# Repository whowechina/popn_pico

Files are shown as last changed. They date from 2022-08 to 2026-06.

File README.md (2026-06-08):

# Popn Pico - Pop'n Music Style Mini Controller
[点这里可以切换到中文版](README_CN.md)

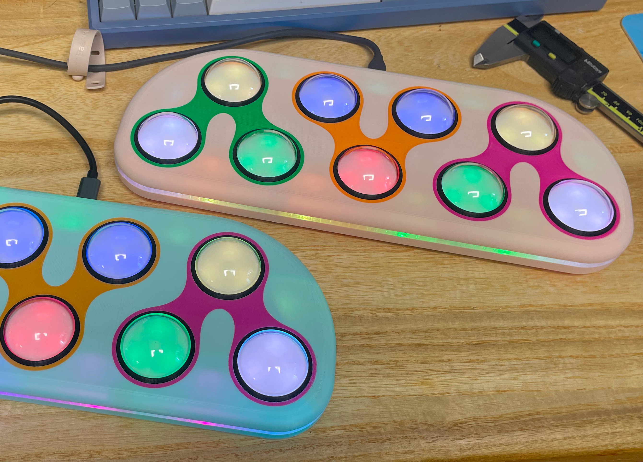
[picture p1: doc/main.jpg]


I've made two generations of Popn Pico. The latest is Popn Pico 2. It's larger than the first generation.

The document here is for the latest generation. The files for the first generation are archived in `Gen1Archive` folder. This is what the first generation looks like.  
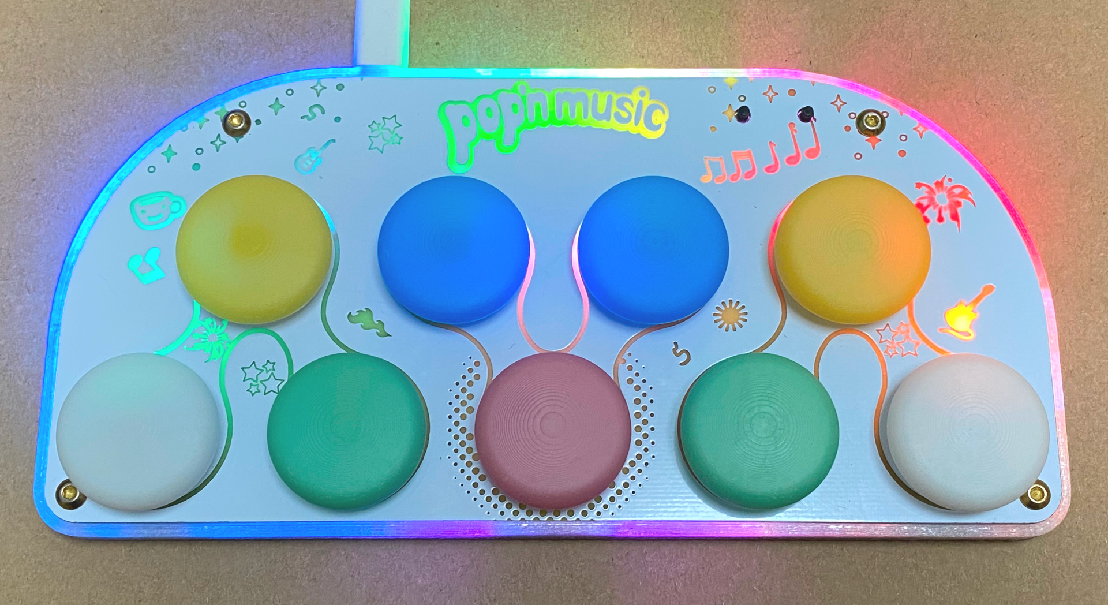
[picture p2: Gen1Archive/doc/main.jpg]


Features:
* It uses self-made 40mm dome buttons.
* Full HID light support.
* Command line for configurations.
* All source files open.

Thanks to many respectful guys/companies who made their tools or materials free or open source (KiCad, OnShape, InkScape, Raspberry things).

Special thanks to community projects and developers.
And also these projects:
* RP_Silicon_KiCad: https://github.com/HeadBoffin/RP_Silicon_KiCad
* Type-C: https://github.com/ai03-2725/Type-C.pretty

## About the License
It's CC-NC. So DIY for yourself and for your friend for free, don't make money from it. And plagiarism that doesn’t even dare to mention the original author is not acceptable. Plase note that pooling orders and group buying for raw materials is acceptable. Selling off any leftover components without profit is also acceptable.

If you're interested in buying from me or some kind of commercial use, please contact me (Discord, QQ group, Wechat group or leave your contact in issue section).

## My Discord Invitation
https://discord.gg/M8f2PPQFEA

## My Other Projects
You can check out my other cool projects.

             

* Popn Pico: https://github.com/whowechina/popn_pico
* IIDX Pico: https://github.com/whowechina/iidx_pico
* IIDX Teeny: https://github.com/whowechina/iidx_teeny
* Chu Pico: https://github.com/whowechina/chu_pico
* Mai Pico: https://github.com/whowechina/mai_pico
* Diva Pico: https://github.com/whowechina/diva_pico
* AIC Pico: https://github.com/whowechina/aic_pico
* Groove Pico: https://github.com/whowechina/groove_pico
* Geki Pico: https://github.com/whowechina/geki_pico
* Musec Pico: https://github.com/whowechina/musec_pico
* Ju Pico: https://github.com/whowechina/ju_pico
* Bishi Pico: https://github.com/whowechina/bishi_pico
* Bishi Pico: https://github.com/whowechina/nos_pico

## **Disclaimer** ##
I made this project in my personal time without any sponsorship. I will continue to improve the project. I have done my best to ensure that everything is accurate and functional, there's always a chance that mistakes may occur. I cannot be held responsible for any loss of your time or money that may result from using this open source project. Thank you for your understanding.

## HOW TO BUILD
### PCB and Components
* Go JLCPCB or any PCB vendor you like, make order with the gerber zip files (latest `Production\PCB\popn_pico2_xxx.zip`), regular FR-4 board, black color, **1.6mm** thickness.
* 1x Rasberry Pico Pi Pico or pin-to-pin compatible clones.  
  https://www.raspberrypi.com/products/raspberry-pi-pico
* 1x USB Type-C socket (918-418K2023S40001 or KH-TYPE-C-16P)
* 27x WS2812B-3528 RGB LEDs.
* 9x WS2812B-4020 RGB LEDs (side facing).
* 6x 0603 0.1uF (0.1~1uF all fine) capacitors.
* 2x 0603 5.1kohm resistors.
* 9x Kailh Choc v2 switches, linear 35-50gf ones are recommended. I personally use Kailh White Rain switches.
* 2x ALPS SKHHLWA010 6\*6\*7mm or compatible tactile switches.  
  https://tech.alpsalpine.com/e/products/detail/SKHHLWA010/

* This is how it looks after soldering.  
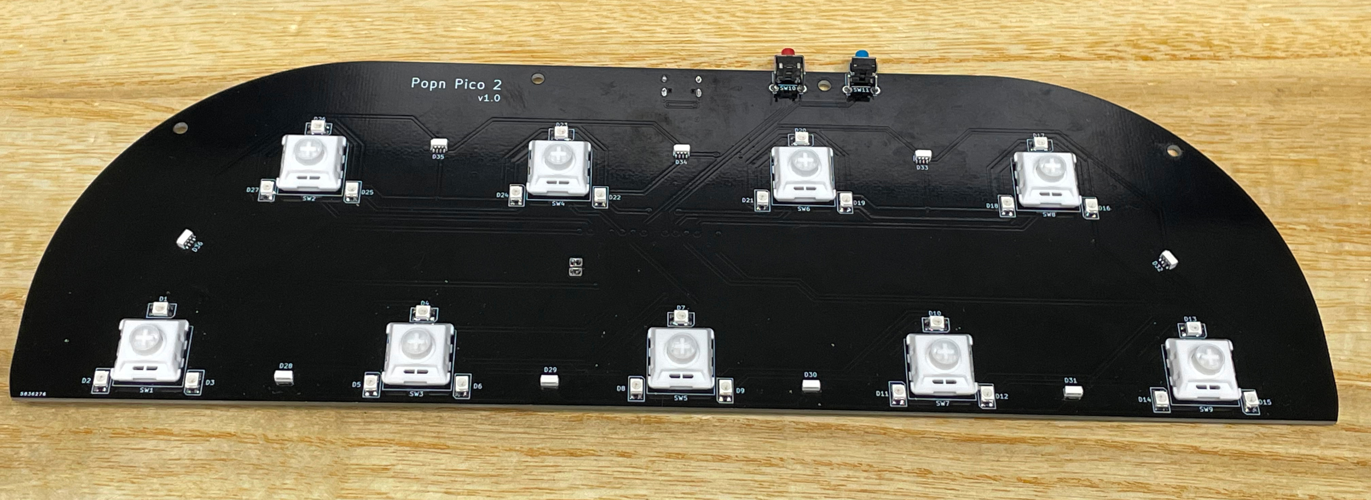
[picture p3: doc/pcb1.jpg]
    
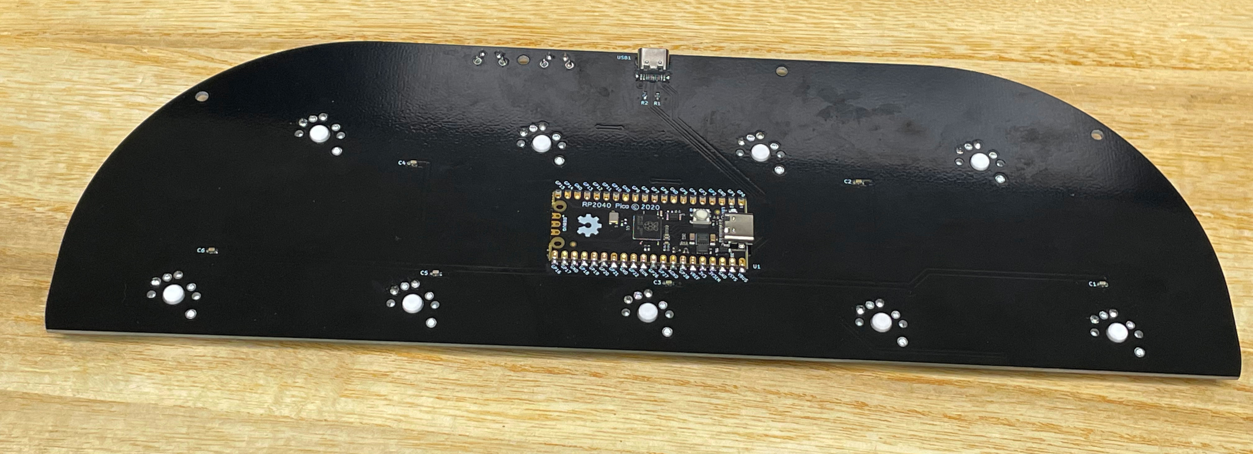
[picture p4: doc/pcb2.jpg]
  

* Becareful of 2 pin holes. It's a common oversight to either forget to solder them or to leave air bubbles during the process. To avoid this, solder slowly from one side of the hole, using minimal solder wire and a generous amount of flux.  
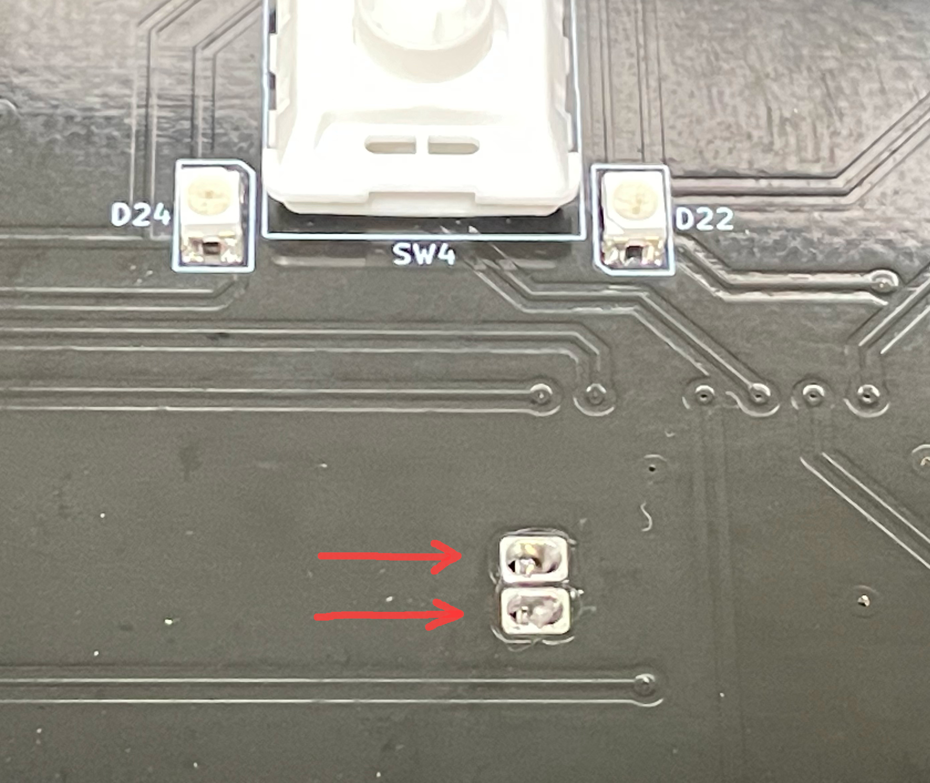
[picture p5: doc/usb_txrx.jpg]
  

### Test the PCB
* You can test the PCB now, put the firmware in.
* LEDs should light up and respond to the button presses.
* Popn Pico should be recognized as a USB HID device, here's the test page.  
  https://whowechina.github.io/iidx_pico/Tools/gamepad_test.html

### 3D Printing
#### Printing parameters  
* PLA or PETG.
* Layer height: 0.2mm
* Wall: >= 3.
* Support: Yes, always, but only on bed and no need for bridges.
* Glue on bed: Yes, it prevents corner warping.
* Files are always in milimeter unit, not inch.

#### Housing Parts
* Base: `Production\3DPrint\popn_pico2_base.stl`. Color is up to you. Support will help the screw holes.
* Middle Support: `Production\3DPrint\popn_pico2_support.stl`, clear transparent.
* Panel: `Production\3DPrint\popn_pico2_panel.3mf`. A multi-color system is highly recommended, so you can choose your favorate colors for each sub-component.

#### 9x Button Seats
* Button Seat: `Production\3DPrint\popn_pico2_button_seat.stl`, white, print upside down.

### Assembly
#### Other components needed
* 9x Chirstmas tree clear plastic balls, 40mm diameter. They come in 2 half-balls, we only need the shorter one.  
  https://www.amazon.com/Plastic-Fillable-Ornaments-Acrylic-Christmas/dp/B09ZTSGL28/
* 8x **M3\*12mm screws** for fixing the housing parts together.
* 8x silicone anti-slip pads (12mm diameter) for the bottom.
* Clear soft/flexible glue or UV curing glue. WARNING: Avoid using any cyanoacrylate-based glue, such as 502. Any glue with a similar smell should also be avoided, as they will leave white smoke marks on the acrylic.

#### Steps
1. We'll make 9 dome button caps first. Just glue the shorter half of the clear plastic ball onto the button seat use the glue mentioned earlier.  
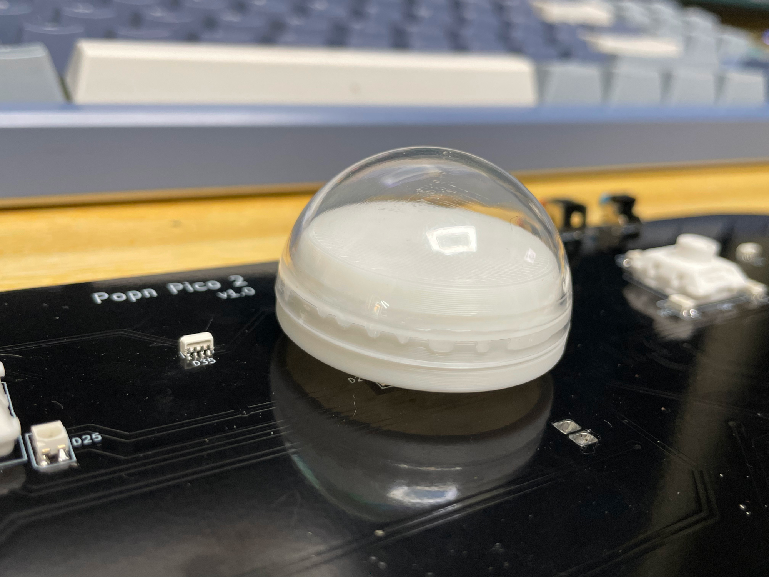
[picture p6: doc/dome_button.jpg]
   
2. Install 9 dome button caps onto the switches.
5. Put the PCB into the base part, and then put on the middle frame, and lastly put on the panel. Tighten them using M3 screws. Put anti-slip pads on the bottom, right on top of the screws.

#### Caution
* Each 3D printer and filament has its own tolerance. If you find the stem holes on the button are too tight, use some needle or knife to enlarge them a little bit.
* Screws are easy to break the 3D printed parts. So don't screw them too fast or too tight. When you notice the resistance suddenly increases, stop screwing.

### Firmware
* UF2 file is in `Production\Firmware` folder.
* For the new build, hold the BOOTSEL button while connect the USB to a PC, there will be a disk named "RPI-RP2" showed up. Drag the UF2 firmware binary file into it. That's it. There's a small hole at the bottom side of the Popn Pico 2, it is facing right to the BOOTSEL button.
* If it's already running Popn Pico 2 firmware, you can either use "update" in command line or hold down more than 4 buttons while connecting to USB to enter update mode.
* To access the command line, you can use this Web Serial Terminal to connect to the command line port of the controller. (Note: "?" is for help)  
  https://whowechina.github.io/iidx_pico/Tools/cli_tool.html

### Usage
* It's very simple. Just plug and play.

### Bonus - Popn Visa Card Holder
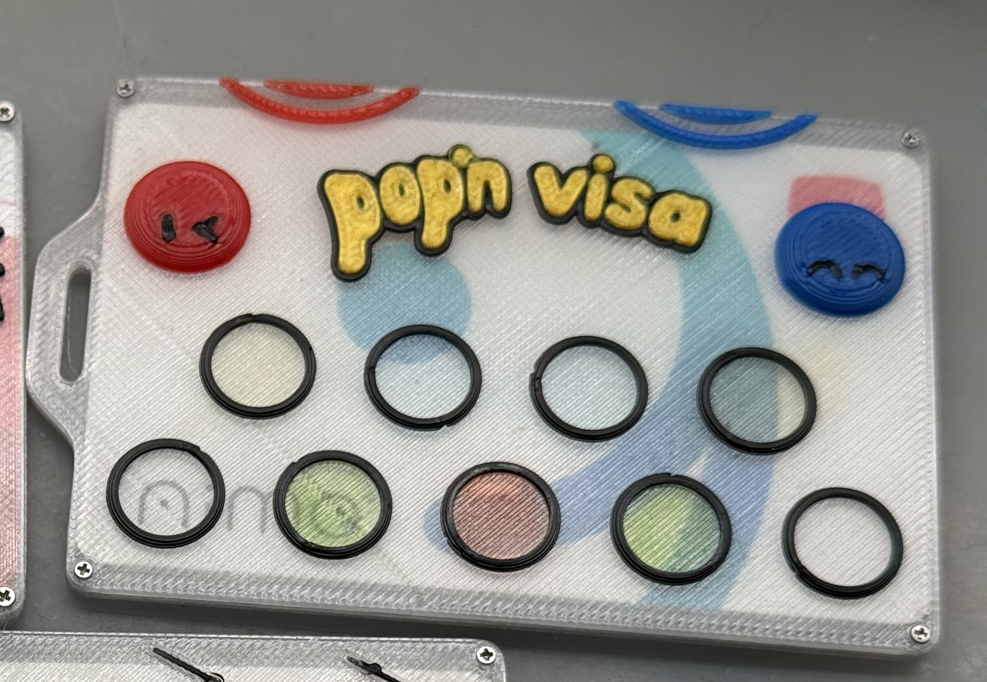
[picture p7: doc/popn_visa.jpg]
   

* Popn Visa card holder is a bonus design for Popn Pico. It can be used to hold your credit card sized arcade cards.
* Print the base and the panel, assign different color for the pattern and text on the panel. `_insert` means it's the heat-set insert version. `_flat` means it's for flat head (countersunk) screws. Transparent material is recommended.
* If you choose the `_insert` version, use 4x M1.2\*1.5mm\*2mm (thread size\*length\*diameter) heat-set inserts on base part.
* 4x M1.2\*3mm screws to fix the panel and the base together. If you choose the `_flat` version, use M1.2\*3mm flat head screws.

## CAD Source File
I'm using OnShape free subscription. It's powerful but it can't archive original designs to local, so I can only share the link here. STL/DXF/DWG files are exported from this online document.  
  https://cad.onshape.com/documents/fcfa3f71e200593febd1451f/w/3452f2d9fccae7d99b53d89a/e/55b4cd1b258679099c74739b

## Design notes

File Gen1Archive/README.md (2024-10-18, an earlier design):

# Pico Popn - Pop'n Music Controller



Features:
* It's tiny.
* 1000Hz polling rate.
* HID lights (9 button lights and Logo RGB).
* RGB rainbow effects.
* Light brightness control (v1.2+).

<video src="https://user-images.githubusercontent.com/11623830/189601050-35440f27-5d67-4410-8533-f4e92887f753.mp4" controls="controls" width="50%">
</video>

<video src="https://user-images.githubusercontent.com/11623830/189601062-6984f811-3431-485f-bb1b-faf98aed2351.mp4" controls="controls" width="50%">
</video>

Thanks to:
* SpeedyPotato, for his great SDVX pico project which inspired me in the first place. I also got many materials from his repo. Check out his great projects: https://github.com/speedypotato.
* CrazyRedMachine, I got panel arts from his SVG files: https://github.com/CrazyRedMachine/PopnPanel.
* Many respectful guys/companies who made their tools or materials free or open source (KiCad, OpenSCAD, InkScape, Raspberry things).

## Notes
For builds v1.1 and earlier, you need to do a small modification and the main PCB to get brightness control with latest firmware.
See the bottom of this document.

## My Other Projects
You can check out my other cool projects.

         

* Popn Pico: https://github.com/whowechina/popn_pico
* IIDX Pico: https://github.com/whowechina/iidx_pico
* IIDX Teeny: https://github.com/whowechina/iidx_teeny
* Chu Pico: https://github.com/whowechina/chu_pico
* Mai Pico: https://github.com/whowechina/mai_pico
* Diva Pico: https://github.com/whowechina/diva_pico
* AIC Pico: https://github.com/whowechina/aic_pico
* Groove Pico: https://github.com/whowechina/groove_pico
* Geki Pico: https://github.com/whowechina/geki_pico
* Musec Pico: https://github.com/whowechina/musec_pico

## **Disclaimer** ##
I made this project in my personal time with no financial benefit or sponsorship. I will continue to improve the project. I have done my best to ensure that everything is accurate and functional, there's always a chance that mistakes may occur. I cannot be held responsible for any loss of your time or money that may result from using this open source project. Thank you for your understanding.

## About the License
It's CC-NC. So DIY for yourself and for your friend, don't make money from it. And plagiarism that doesn’t even dare to mention the original author is not acceptable. Plase note that pooling orders and group buying for raw materials is acceptable. Selling off any leftover components without profit is also acceptable.

If you're interested in some kind of commercial use, please contact me (Discord, QQ group, Wechat group or leave your contact in issue section).

## My Discord Invitation
https://discord.gg/M8f2PPQFEA

## HOW TO BUILD
### Step 1 - Buy
* Place order at jlcpcb.com for PCB and plate. Gerber zip files are **/PRODUCTION/PCB.zip** and **/PRODUCTION/PLATE.zip**. Leave everything default in JLC's ordering page (board thickness is 1.6mm). Choose what ever color you like, I prefer white.  
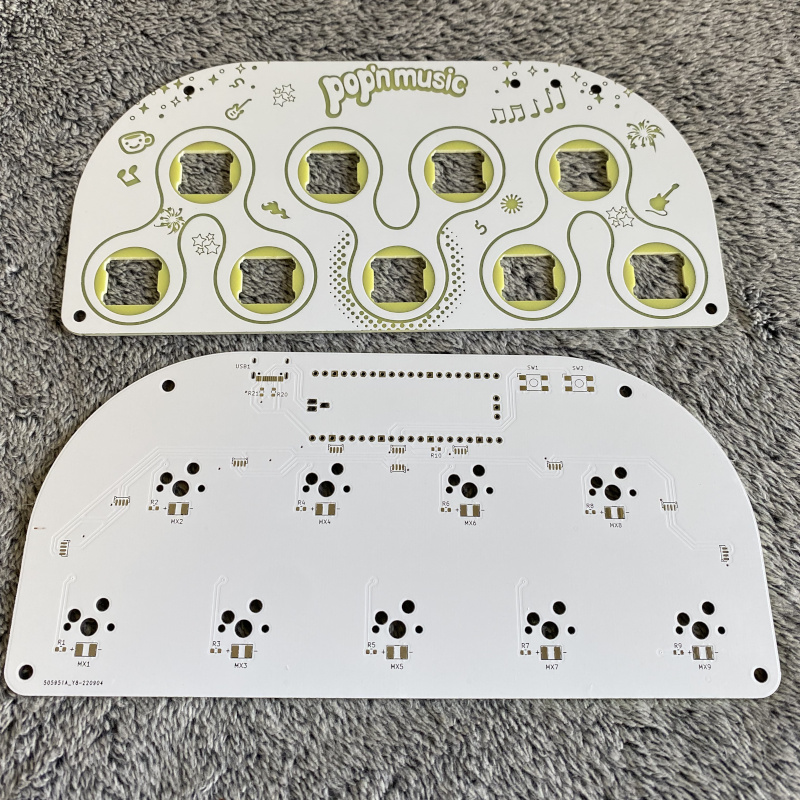
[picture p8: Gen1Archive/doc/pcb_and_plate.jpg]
  

* Order 3D printing service for the case, FDM with transparent PETG filament or SLA with half-transparent resin. If you own a 3D printer, do it yourself. The file is **/PRODUCTION/pico_popn_case.stl**.  
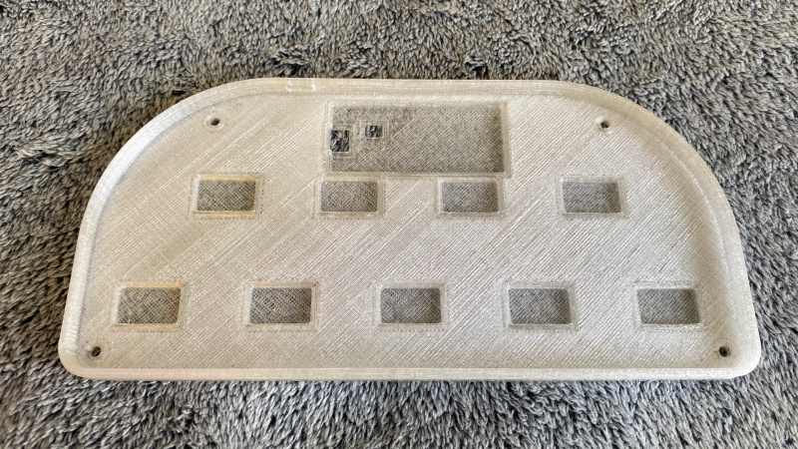
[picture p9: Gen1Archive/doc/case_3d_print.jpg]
  

* Buy other components (get few more for tolerance):
  * 1 * Raspberry Pi Pico (https://www.raspberrypi.com/products/raspberry-pi-pico/)
  * 9 * Gateron Hotswap Sockets (https://www.gateron.co/products/gateron-hot-swap-pcb-socket)
  * 9 * Gateron 3.4mm-travel switches (I prefer Box CJ Switch, https://www.keychron.com/products/gateron-box-cj-switch)
  * 1 * USB Type-C socket (918-418K2023S40001 or KH-TYPE-C-16P)
  * 10 * WS2812B-4020 side-facing RGB LEDs
  * 9 * 2835 white LEDs (0.2W or 0.5W)
  * 10 * 0603 220ohm resistors
  * 2 * 0603 5.1kohm resistors
  * 2 * Tactile Switches (4.5x4.5x6.5mm or 4.5x4.5x7mm or KAN4542-0701C)
  * 4 * set of M3 screws/nuts/spacers (I'll explain later)
  * 9 * Keycaps (many choices I'll explain later)

### Step 2 - Solder
* Use the smallest soldering iron tip you have.
* Use solder flux, always keep the pins "wet".
* Soldering iron temperature set to around 300°C.
* Use tweezers to hold components.
* Tricks for Type-C socket and 4020 RGB LEDs.
  * Put flux on all those small pins. Melt a tiny little bit solder (seriously very very little bit) at the iron tip. Then quickly solder the pins. Flux and very little bit solder is the key.
* 2 resistors near USB socket are 5.1k ohm, others are all 220ohm.
* Don't forget to solder 3 "holes" which connects to the Raspberry Pi Pico's USB pins.  
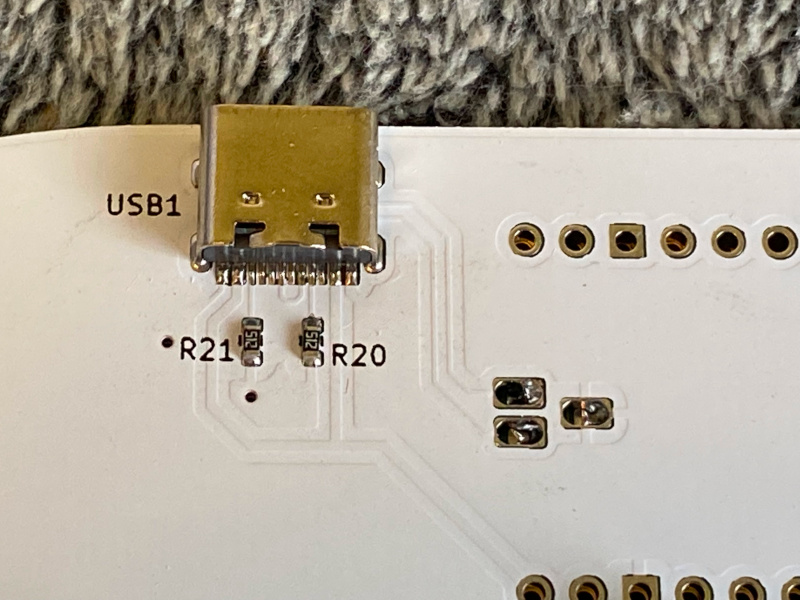
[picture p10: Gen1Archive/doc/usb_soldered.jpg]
  
* 4020 RGB LEDs are side-facing, don't make it "up-facing".  
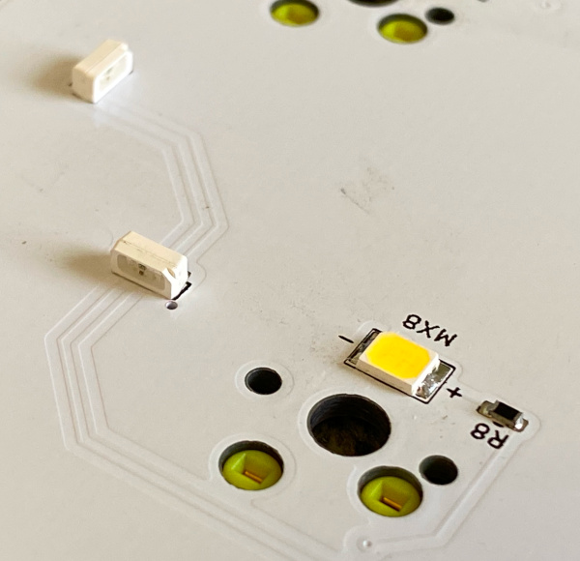
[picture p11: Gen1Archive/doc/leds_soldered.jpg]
  
* They look like this when finish:  
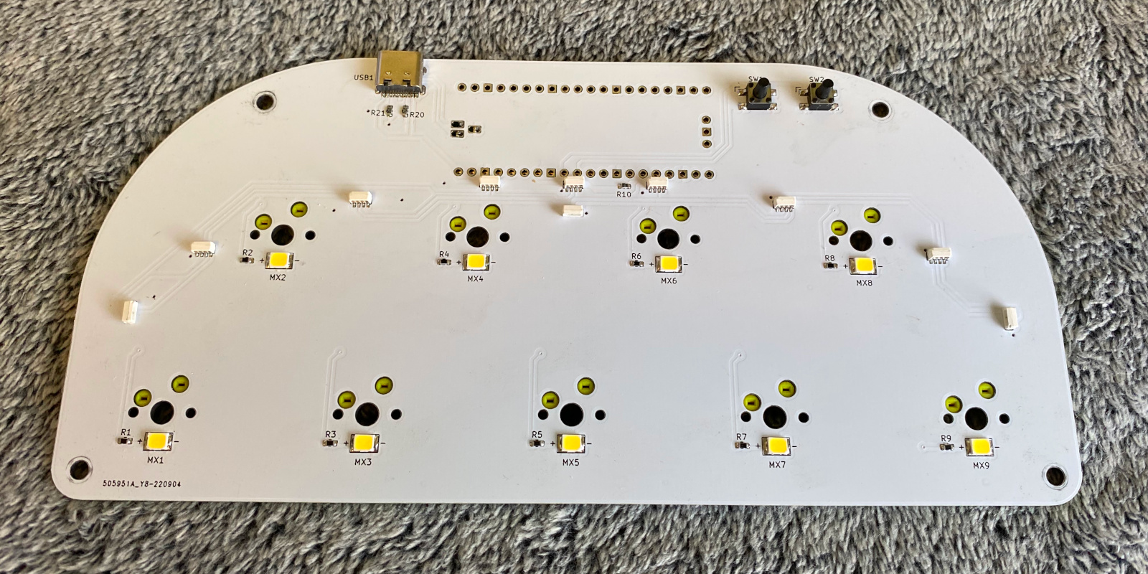
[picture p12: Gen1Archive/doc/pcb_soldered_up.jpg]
  
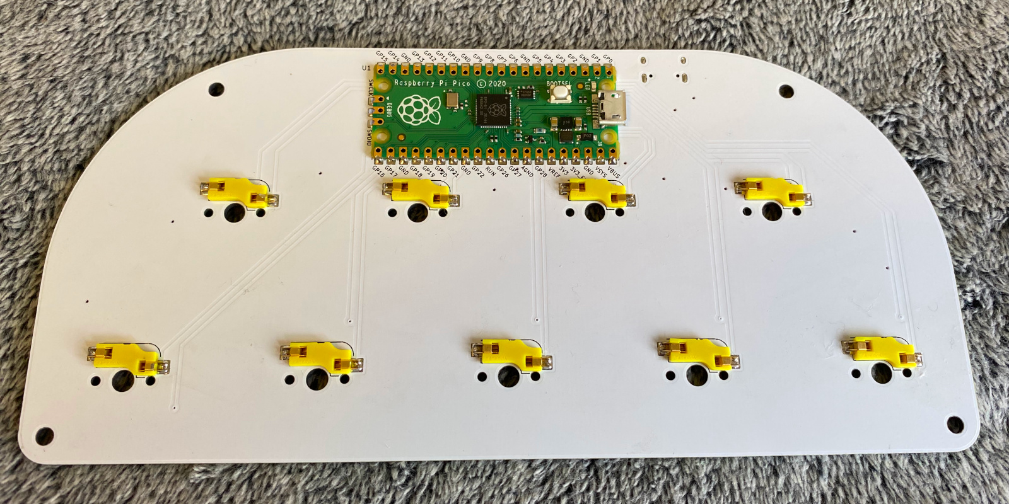
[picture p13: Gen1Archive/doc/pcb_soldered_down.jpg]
  

### Step 3 - Firmware
* Use a USB cable to connect the PCB to a PC/Mac computer while pressing down the small button on Raspberry Pi Pico. An explorer window will pop up. If it doesn't show up, navigate to a disk labeled "RPI-RP2".  
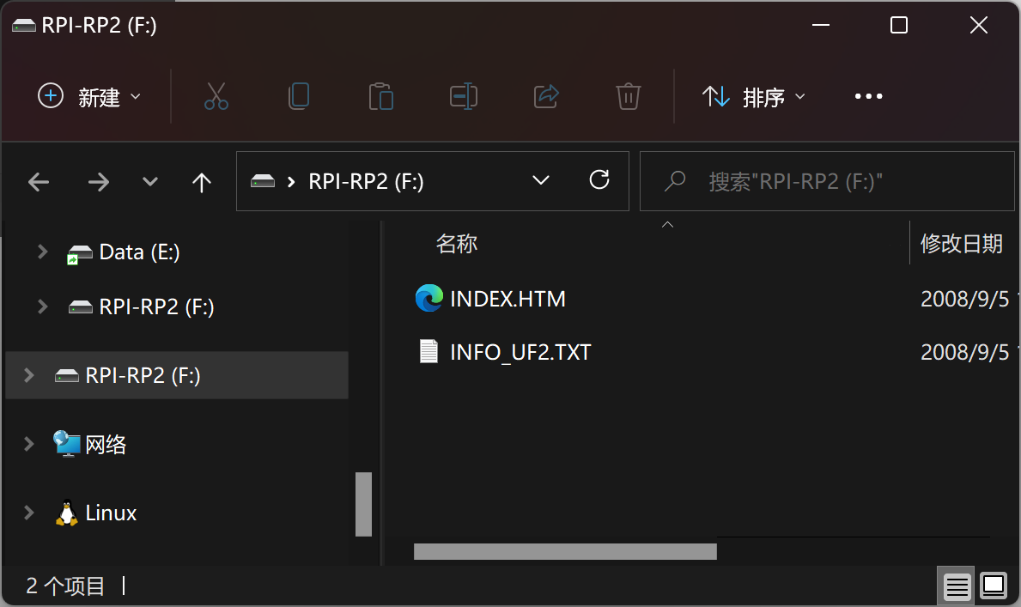
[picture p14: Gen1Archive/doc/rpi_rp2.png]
  
* Drag the UF2 file (**/PRODUCTION/pico_popn.uf2**) to the root of this new disk.
* The RGB lights will start rainbow effects.
* If it's not working, go back to Step 2 and fix it.

### Step 4 - Assembly
* Insert 9 key switches into the plate, be careful, don't bend the leads.  
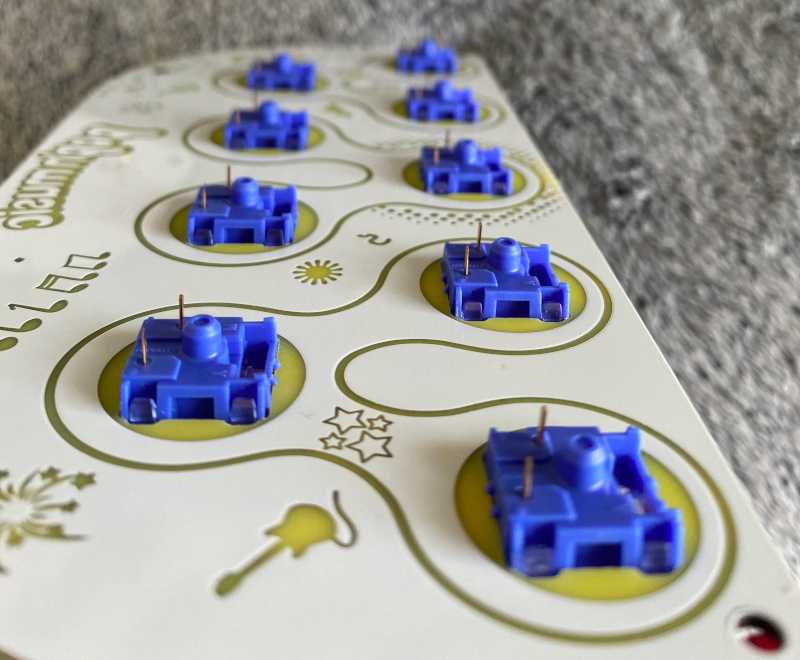
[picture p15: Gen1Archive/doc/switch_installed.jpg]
  
* Put the PCB into the case.
* Gap between the plate and the PCB is about 3.4mm. There're many ways to fix and fasten boards and case. Here's my solution, I reprocessed the screws and spacers as they didn't come with proper length.  
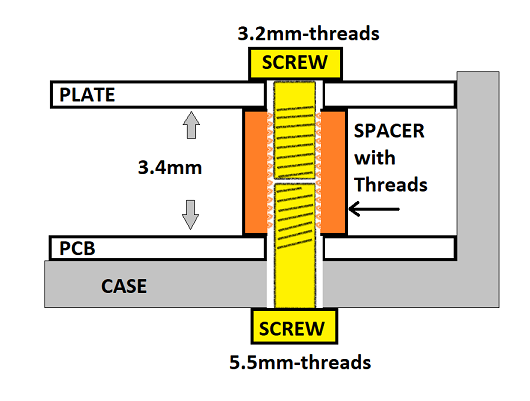
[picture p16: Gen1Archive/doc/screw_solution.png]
  
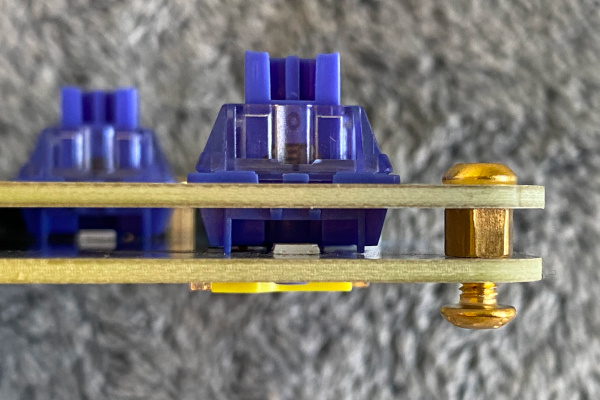
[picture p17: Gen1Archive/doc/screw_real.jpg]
  
* Another way is to use a long M3 screw from top side and a nut at the bottom side. Between PCB and plate, use a 3.5mm length M3 spacer with no threads. You can also 3D print some spacers using provided **/PRODUCTION/screw_spacer.stl**. 
* Don't forget get some anti-slip silicone pads.  
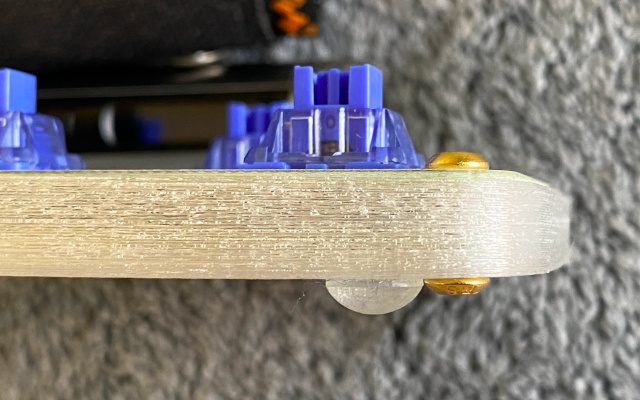
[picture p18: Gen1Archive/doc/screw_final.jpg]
  
* Almost done.  
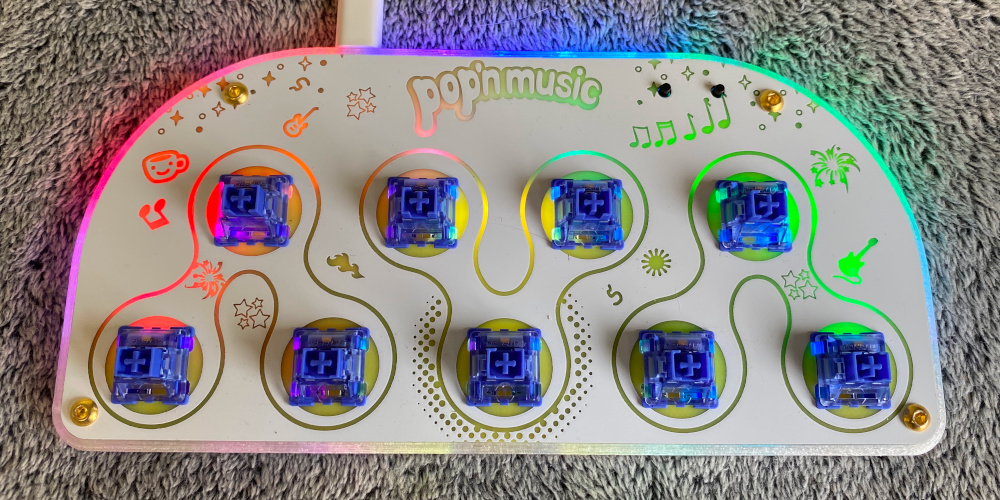
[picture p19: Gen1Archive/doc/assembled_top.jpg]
  
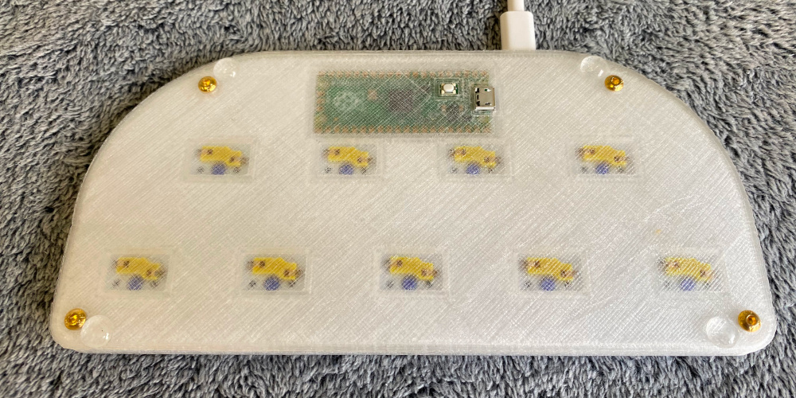
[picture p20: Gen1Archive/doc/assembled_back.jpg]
  

 ### Step 5 - Keycaps
 * If you have resin printer, you can make them by yourself.
   * Make half-transparent resin by mixing translucent and white resin (2:1) as the base resin.
   * Mix some drops of UV resin pigment, you can make all Pop'n Music button colors.  
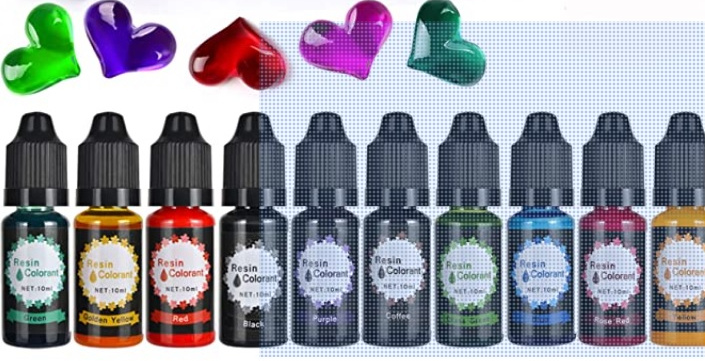
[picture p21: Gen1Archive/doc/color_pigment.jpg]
     
   * 3D file is **/PRODUCTION/popn_keycap.stl** or if you're using Chitubox - **/PRODUCTION/popn_keycaps.chitubox**. Orientation and support should be like this to get perfect button surface.  
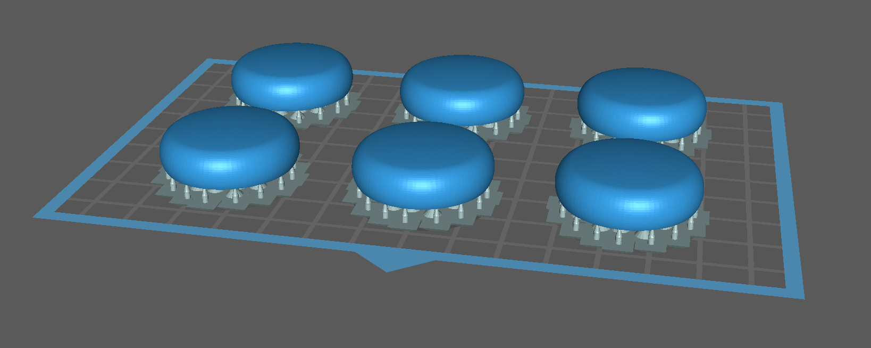
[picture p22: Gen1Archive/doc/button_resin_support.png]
     
   * These are printed by my Elegoo Mars 3 Pro.  
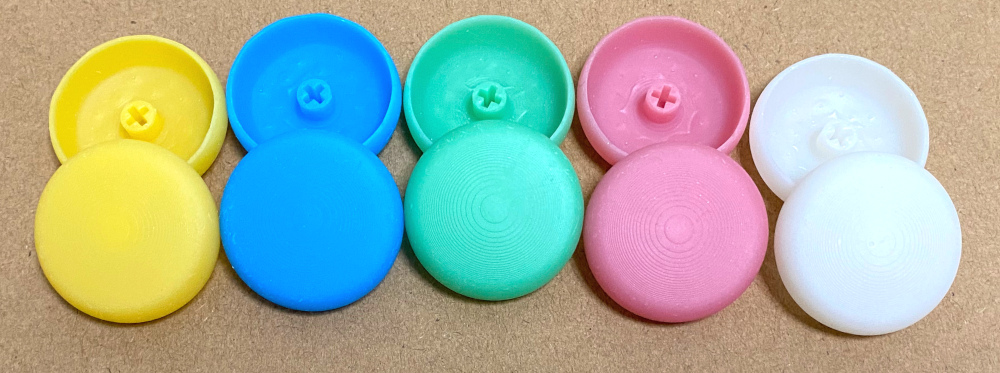
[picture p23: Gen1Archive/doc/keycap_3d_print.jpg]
     
* There're many other choices.
  * Homemade bottle cover keycaps  
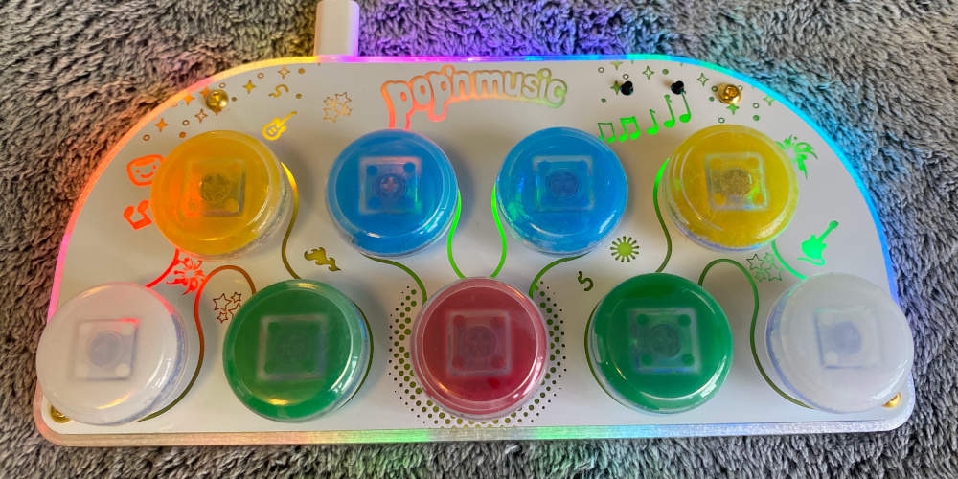
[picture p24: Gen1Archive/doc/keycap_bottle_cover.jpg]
    
  * Homemade coat buttons keycaps  
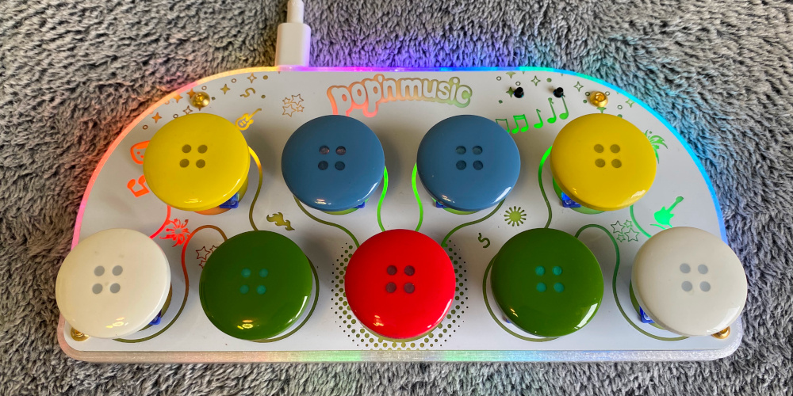
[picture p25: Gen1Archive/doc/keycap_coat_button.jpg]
    
  * DSA color keycaps  
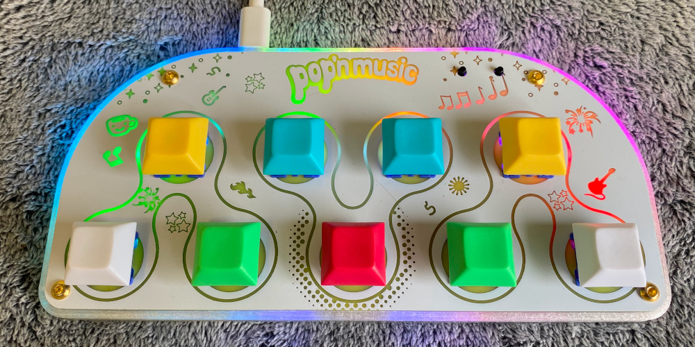
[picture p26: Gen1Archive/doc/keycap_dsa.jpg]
    
  * DSA transparent keycaps  
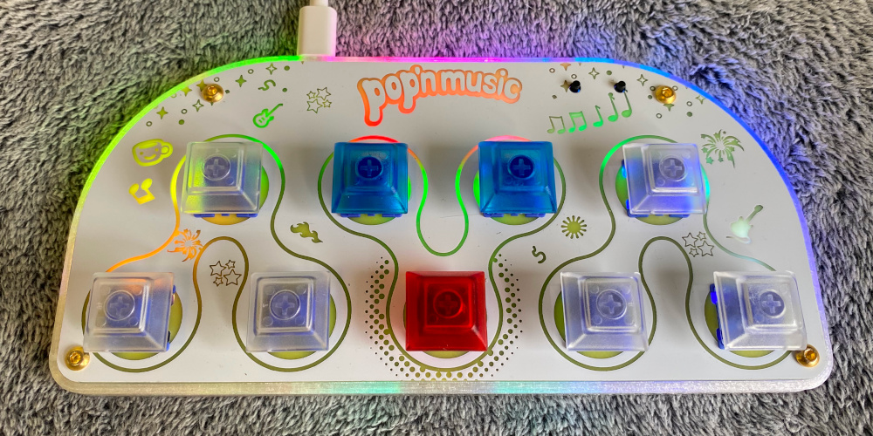
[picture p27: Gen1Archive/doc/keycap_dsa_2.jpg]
    
  * MA color keycaps  
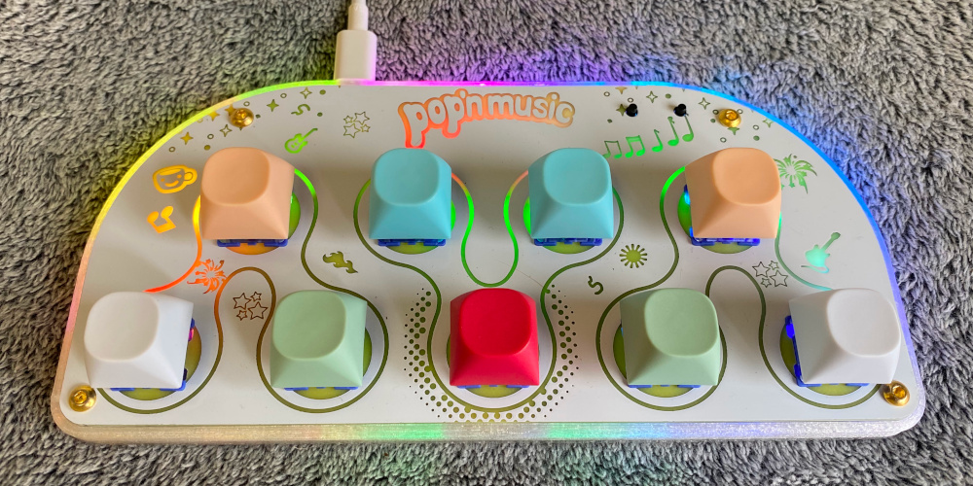
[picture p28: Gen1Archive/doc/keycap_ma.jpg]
    
  * XDA 1.5U color keycaps  
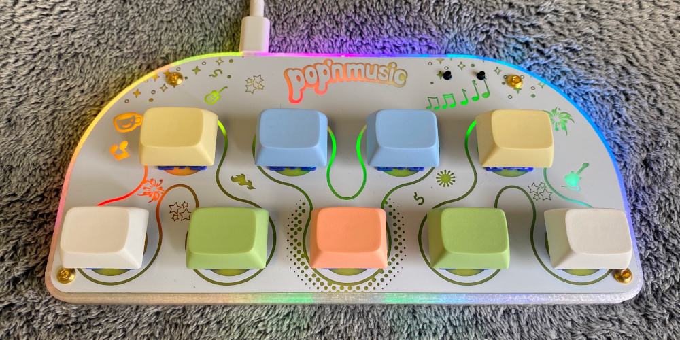
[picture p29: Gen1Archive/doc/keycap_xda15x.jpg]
    
  * About the homemade process.
  * I bought these inexpensive 3gram/5gram distribution bottles just to get the covers (28-30mm diameter).  
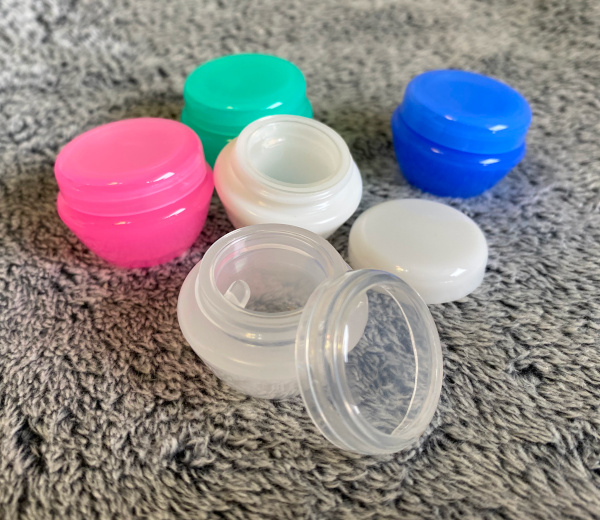
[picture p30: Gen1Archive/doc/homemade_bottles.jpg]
    
  * Cut the shaft/socket out of regular transparent keycaps.  
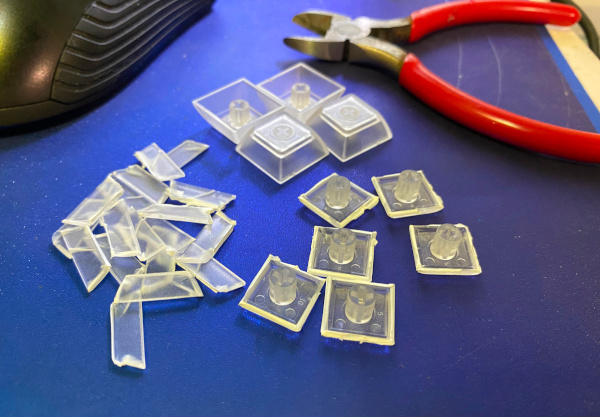
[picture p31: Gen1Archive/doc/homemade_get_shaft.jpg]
    
  * Drill some holes on them so later we can apply UV resin better.  
    
  * Apply UV resin, glue the socket and the cover together.  
    
    
  * Don't forget alignment.  
    
  * After cured by UV light, they look like this:  
      

## Modification for v1.1 and earlier PCB
In the first version of main PCB (v1.1 and earlier) I chose a wrong GPIO for the button 9 LED which caused a PWM conflict. To support brightness and fading control, that must be fixed.  
The idea is to cut the old LED 9 track and wire it to a different pin (GPIO18). The blue * mark in the picture means "to cut the track" and the red * mark means "to solder".  
If you don't need brightness and fading control, you don't need make this modification, just use v1.1 firmware.
Sorry for the mistakes I made.




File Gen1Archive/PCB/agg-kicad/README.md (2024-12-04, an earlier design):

# @adamgreig's KiCAD Library

This repository contains my collection of KiCAD symbols, footprints,
and related files.

Every symbol and footprint is very carefully checked against either the
relevant standard (generally IPC-7351B) or specific manufacturer footprints.
Many are procedurally generated from a simple set of dimensions, which ensures
consistency and correctness. My objective is to have a useful collection of
correct parts that all look consistent and work well together.

I encourage other people to use these parts; they're all licensed under a
permissive MIT licence and it's easy to simply copy one or two files from the
repository, or submodule the entire repo.

Contributions are also very welcome; please open a pull request and I will
carefully review the proposed additions. All contributions are likewise
licensed under the MIT licence.

A number of automatic rules are checked against every footprint and symbol on
each commit by the build system. The current status is:


## Schematic Symbols

To use, add relevant `.lib` files to your project libraries. There is one 
`.lib` file per symbol.

Alternatively add `agg-kicad.lib` from the root directory, which includes all 
symbols. This file is built using `scripts/compile_lib.py` and kept up-to-date 
automatically.

Each part contains supplier order codes and manufacturer part numbers where 
possible and sensible. Parts are drawn as per the conventions in 
`lib/README.md`, based on the KiCAD project conventions.

Symbols for many ICs and other "black-box" parts are drawn automatically from
`.yaml` files in the relevant directories, using the `build-lib-ic.py` script.
Check some of these out for an example of the syntax etc.

Check the README in each library folder for details and notes on each part.

## PCB Footprints

To use, add `agg.pretty` to your project libraries, with nickname `agg` 
recommended for compatibility with the schematic symbols.

Where possible footprints are based on the appropriate standards and follow the 
conventions in `agg.pretty/README.md`, based on the KiCAD project conventions.

Many footprints for 2-terminal chip devices and 2- or 4- row SMD ICs are 
automatically generated using the `build-mod-chip.py` and `build-mod-ic.py` 
scripts, which contain the parametric specifications for all the footprints 
they should build. This includes things like 0402 resistors, DFN and QFP ICs, 
and similar sorts of footprints.

## StickerBOM

StickerBOM is a script to convert your BOM into a PDF to print onto sticker 
labels, one label per BOM item. The labels have a drawing of the PCB to show 
you where that item goes, which makes hand assembly a lot nicer!

Check the [wiki page](https://github.com/adamgreig/agg-kicad/wiki/StickerBOM) 
for more information on StickerBOM.

## Scripts

See the README in the scripts folder for detailed information on each script.

The only requirement is PyYAML for some of the build scripts:
`sudo pip install pyyaml` or similar.

## Makefile

You can use the Makefile to:
* Rebuild all built-from-parameter files with `make build`
    * Just libraries with `make build-libs`
    * Just modules (footprints) with `make build-mods`
* Verify all built-from-parameter files are up-to-date with `make build-verify`
* Recompile all compiled outputs (the combined `.lib` and the `.pro`) with 
  `make compile`
* Verify all compiled outputs are up-to-date with `make compile-verify`
* Verify both built and compiled outputs with `make verify`
* Check all files against rules with `make check`
    * Just libraries with `make check-lib`
    * Just modules with `make check-mod`

Travis-CI is configured to run `make check` and `make verify` and reports the 
resulting status as the build status:


Additionally in `scripts/` is `pre-commit` that stops any commits that do not 
pass `make check` and `make build-verify`, and `post-commit` that runs `make 
compile-verify` and if any compiled files are not up to date, recompiles them 
and commits the result. Copy these to `.git/hooks` for use.

## Licence

All content licensed under the MIT licence. See `LICENSE`.

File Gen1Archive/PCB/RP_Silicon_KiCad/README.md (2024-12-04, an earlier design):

# RP\_Silicon\_KiCad
KiCad resources to help create designs using the Raspberry Pi MCUs

This first upload is extracted unaltered from:

* [https://datasheets.raspberrypi.org/pico/RPi-Pico-R3-PUBLIC-20200119.zip](https://datasheets.raspberrypi.org/pico/RPi-Pico-R3-PUBLIC-20200119.zip)
* [https://datasheets.raspberrypi.org/pico/RPi-Pico-R3-PUBLIC-20200119.zip](https://datasheets.raspberrypi.org/pico/RPi-Pico-R3-PUBLIC-20200119.zip)

This provides the Pico and the RP2040 library & footprint files respectively.

Keep these files out of the KiCad directories so they don't get overwritten by any updates. I have the KiCadLibraries in my Documents folder so that macOS will iCloud sync automagically for me. You can do similar on other OS's.

Set the location of this folder in both the Manage Symbol Libraries and the Manage Footprint Libraries menu options from the Preferences menu.

If you are not sure about this, see [Install.md](Install.md)

These libraries may be included in the main set of KiCad libraries at a later point, at which time I'll look to see if there is a need to maintain this repro.

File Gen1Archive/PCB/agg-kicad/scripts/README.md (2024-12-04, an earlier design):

# agg-kicad scripts

You'll probably need to install PyYAML first:
`sudo apt-get install python-yaml` or `sudo pip install pyyaml` or so on.

## Builders

These scripts generate `.lib` and `.kicad_mod` files based on parameters inside 
the script. They typically are used to automate creation of tedious or similar 
parts.

Run with `--verify` as the final argument to instead verify that the existing 
compiled file is up-to-date (returns exit status 0 if up to date, 1 otherwise).

### build_lib_connector.py

This script generates `conn.lib` containing a number of similar connectors with 
different numbers of pins.

`python3 build_lib_connector.py ../lib/connectors/conn.lib`

### build_lib_ic.py

This script generates multiple `.lib` files, one per IC, configured by `.yaml`
files inside the library path you point it at.

`python3 build_lib_ic.py ../lib/`

### build_lib_power.py

This script generates `power.lib` containing a number of power symbols with 
different names, such as `VCC`, `VDD`, `3v3`, `GND`, `DGND`, etc.

`python3 powerlib.py ../lib/power/power.lib`

### build_mod_chip.py

Generate IPC-compliant chip packages. The list of packages to generate and 
their parameters are specified at the start of the file.

`python3 build_mod_chip.py ../agg.pretty/`

### build_mod_ic.py

Generate IC footprints for dual and quad packages. The list of packages to 
generate and their parameters are specified at the start of the file.

`python3 build_mod_ic.py ../agg.pretty/`

### build_mod_jstpa.py

Generate JST-PA connector footprints in top/side entry, pth and smd, in 
different pin counts.

`python3 build_mod_jstpa.py ../agg.pretty/`

## Checkers

These scripts check `.lib` and `.kicad_mod` files against a set of rules. They 
return with exit code 0 if all checks passed.

### check_lib.py

This script checks all the `.lib` files in a directory and validates that they 
conform to as many of the rules as can reasonably be automatically checked.

The top of the file includes a list of library files that are automatically 
generated, which are allowed to include more than one part per library.

Some exceptions can be enabled inside a library file, for example 
`#invisiblename` for parts where the name is allowed to be invisible and 
`#invisiblereference` where the reference may be invisible.

`python3 libcheck.py ../lib`

### check_mod.py

This script checks footprint module files in a directory against consistency 
rules.

`python3 scripts/modcheck.py agg.pretty`

## Compilers

These scripts generate an output by combining many existing files.

Run with `--verify` as the final argument to instead verify that the existing 
compiled file is up-to-date (returns exit status 0 if up to date, 1 otherwise).

### compile_lib.py

This script generates a single `agg-kicad.lib` file containing all the 
schematic symbols in all the individual `.lib` files.

Run with `--verify` as the final argument to instead verify that the existing 
compiled library is up-to-date.

`python3 compilelib.py ../lib ../agg-kicad.lib`

### compile_pro.py

This script creates a blank KiCAD project file containing all the schematic 
libraries in the given directory. Useful for generating a development project 
for editing schematic symbols.

`python3 genproject.py ../lib ../agg-kicad.pro`

## Other Scripts

### xml2bom.py

This script converts a KiCAD `.xml` BOM into a text file containing:
* Any detected problems, such as duplicate parts with different order codes
* Quick-paste format order BOMs for each detected supplier
* Assembly BOM with further details on every part

To use, add this line to your BOM scripts:

`python3 "/path/to/agg-kicad/scripts/xml2bom.py" "%I" "%O.bom"`

### pre-commit

This script is a Git hook that should be placed in `.git/hooks`. It will:

* Check that all built objects are up to date, stopping the commit if not
* Check that all the checks pass, stopping the commit if not

### post-commit

This script is a Git hook that should be placed in `.git/hooks`. After any 
commit it will check any compiled objects are up to date, and rebuild and 
commit them if not.

### moddraw.py

Render `.kicad_mod` files to PNGs. Used by `modreport.py` to generate images 
for the report.

### modreport.py

Generate an HMTL report of all the modules in a library, including rendered 
images. Not currently very sophisticated or automated.

### panelise.py

Step-repeat a `.kicad_pcb` PCB with a given pitch and number of repeats, 
generating a new `.kicad_pcb` file. Does not yet support any additional 
panelisation features like tabs, alignment holes, fiducials, etc.

`python3 panelise.py /tmp/in.kicad_pcb 2 30 2 10 /tmp/out.kicad_pcb`

## Utility Modules

### sexp.py

Parse and generate s-expressions for KiCAD pcbnew files.

### kicad_mod.py

Helper functions for generating `.kicad_mod` files.

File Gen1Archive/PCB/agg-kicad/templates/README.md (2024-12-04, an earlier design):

# PCB Templates

This directory contains templates for commonly-used PCB shapes (shields, hats, etc.)

## Using a Template

After creating your project, replace the `.kicad_pcb` file with the template. When
you're ready to start layout, open the PCB file and set the reference of the
connector(s) to match the reference in your schematic. Then continue as normal.

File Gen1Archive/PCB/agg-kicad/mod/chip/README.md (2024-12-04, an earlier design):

Name format is `SIZE[-SPECIAL]`. Examples: `0402`, `0603-LED`

## Keys
* *name*: Name
* *pad_shape*: [width, height] of the pads
* *pitch*: spacing between pad centres
* *chip_shape*: [width, height] of the chip (for Fab layer)
* *pin_shape*: [width, height] of chip pins (for Fab layer).
  Use negative widths for internal pins (e.g., chip resistors)
* *silk*: "internal", "external", "triangle", "internal_pin1", "external_pin1", or None.
  What sort of silk to draw. Default is "internal".
* *courtyard_gap*: minimum distance from footprint extreme to courtyard.
  If not specified, the default ctyd_gap is used.
* *model*:``
  {"path": <str>,
    "offset": [x,y,z],
    "scale": [x,y,z],
    "rotate": [x,y,z]}
``
   Defines which 3D model to associate with the footprint.

Except where otherwise noted, all packages are in IPC nominal environment.

Chip drawings are nominal sizes rather than maximum sizes.

All lengths are in millimetres.

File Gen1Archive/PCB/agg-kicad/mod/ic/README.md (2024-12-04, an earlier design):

Names in the following format: `FAMILY-PINS[-MOD][-EP][-SPECIAL]`

MOD might be "W" for wide.

SPECIAL might refer to a manufacturer's specific modified footprint.

Examples: SOIC-8, SOIC-16-W, QFN48-EP

Unless otherwise noted, all pad dimensions are as per IPC-7351B nominal,
while fab layer annotatons are as per IPC-7351B package maximums.

## Keys (QFN/QFP/DFN/DFP)

* `rows`: either 2 or 4, for dual or quad packages.
* `pins`: total number of pins
* `pins_first_row`: optional when rows is 4, number of pins in row containing
  pin 1, for rectangular chips. Must also give `row_pitch` as a tuple. Defaults
  to pins/rows i.e. a square chip. Not applicable to 2-row chips.
* `row_pitch`: spacing between centres of rows of pins, or tuple of
  [horizontal pitch, vertical pitch] only if `pins_first_row` is given,
  where horizontal pitch is pin 1 to its opposite pin.
* `pad_shape`: (width, height) of a pad for a pin.
* `ep_shape`: (width, height) of an exposed pad underneath the chip.
  Leave out this parameter to skip the exposed pad.
* `ep_mask_shape`: (width, height, w_gap, h_gap) of mask apertures on EP.
  Multiple apertures will be created to fill. Leave out this parameter to cover
  the EP in mask aperture.
* `ep_paste_shape`: (width, height, w_gap, h_gap) of paste apertures on EP.
  Multiple apertures will be created to fill. Leave out this parameter to cover
  the EP in paste aperture.
* `ep_vias`: (drill, size, gap) of via hits to put in the EP.
  Leave out this parameter to not place any vias.
* `pin_shape`: (width, height) of the chip package pins (for Fab layer).
     Use negative widths for internal pins (e.g., QFNs).

## Keys (BGA only)

* `rows`: number of rows (identified by letters)
* `cols`: number of columns (identified by numbers)
* `pad_shape`: diameter of a pad for a pin.
* `mask_shape`: diameter of solder mask opening for a pin.
* `pin_shape`: diameter of the chip package pins (for Fab layer).
* `letters`: Optional string of sequential letters to use naming rows,
  defaults to standard ABCDEFGHJKLMNPRTUVWY.

## Keys (Common)

* `name`: Name to generate footprint under
* `description`: Footprint description
* `skip_pins`: optional, list of pin numbers to skip (leaving remaining pins in
  sequential order). Generates packages like SOT-23-3. Each list entry may be
  an exact pin to skip (eg 12 or B6) or a range of numbers or letters or both
  (eg 5-8 or B3-5 or A-C6 or A-C3-5)
* `pin_pitch`: spacing between centres of adjacent pins.
* `chip_shape`: (width, height) of the actual chip package (for Fab layer).
* `silk`: "internal" or "external" or None. Default is "internal" unless
  `ep_shape` is given in or on BGAs in which case default is "external".
* `model`: dictionary containing `path` string to 3d model, and optional
  `offset`, `scale`, and `rotate` lists of [x, y, z] values.

All lengths are in millimetres.

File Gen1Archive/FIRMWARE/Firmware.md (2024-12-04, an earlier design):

Firmware for Popn Pico now has a separate repository, go check it out.
https://github.com/whowechina/popn_pico_firmware

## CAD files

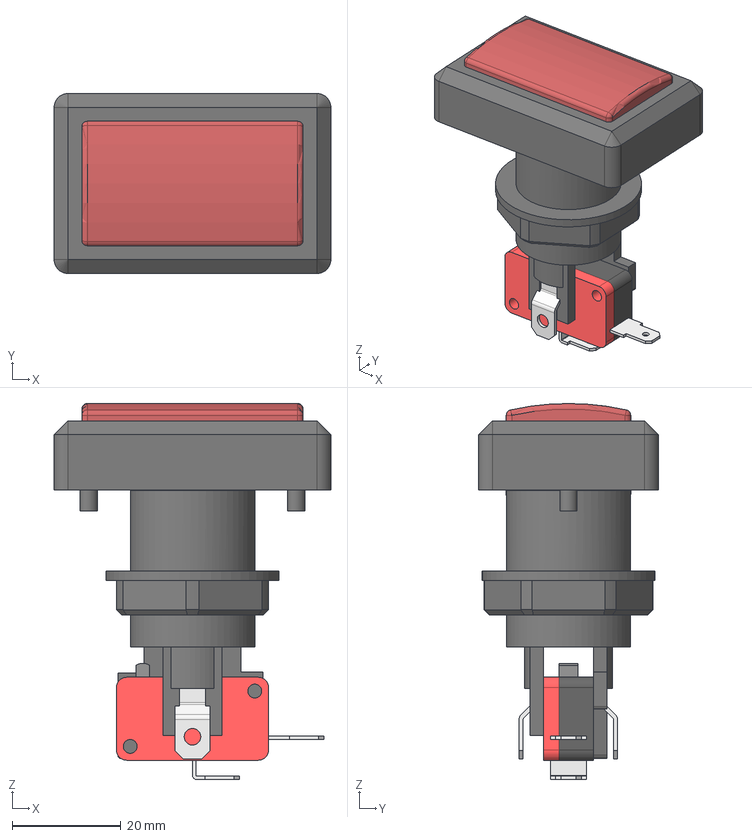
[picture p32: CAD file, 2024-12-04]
PCB/Popn2/3dmodels/Credit Button Assy (Groovy).step
50.8 x 33.0 x 69.0 mm
Button
Nut
Switch

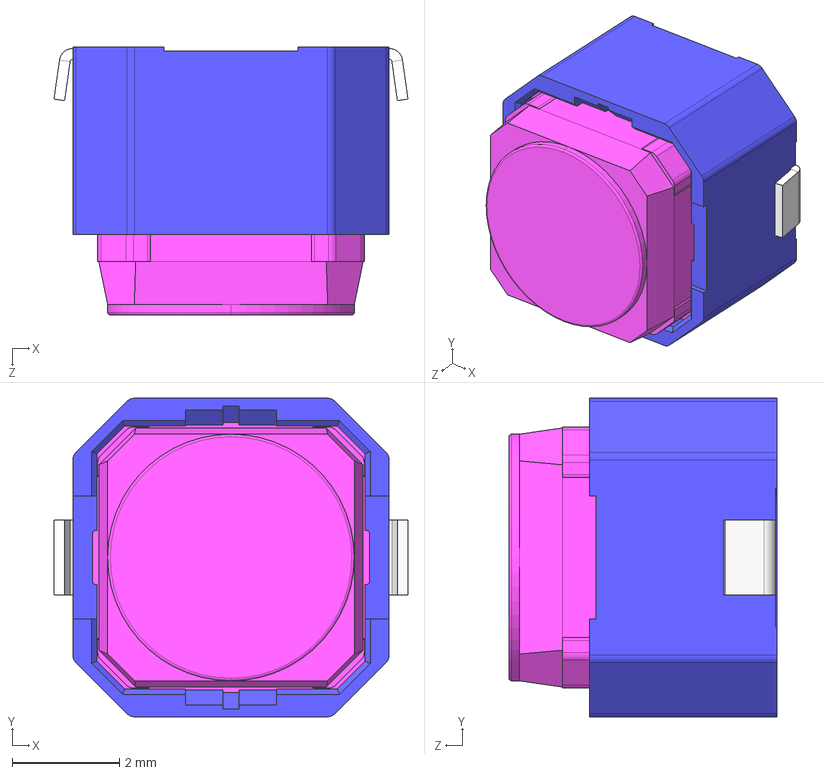
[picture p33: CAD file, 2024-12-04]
PCB/Popn2/3dmodels/SKPMAM.STEP
6.60 x 5.94 x 5.00 mm

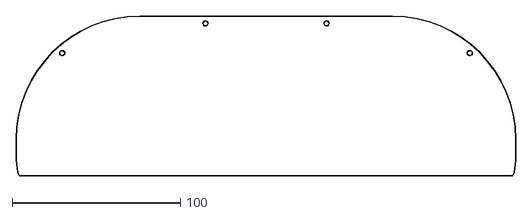
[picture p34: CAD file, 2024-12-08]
PCB/Popn2/Popn Pico 2 - PCB.dxf
297.0 x 95.0

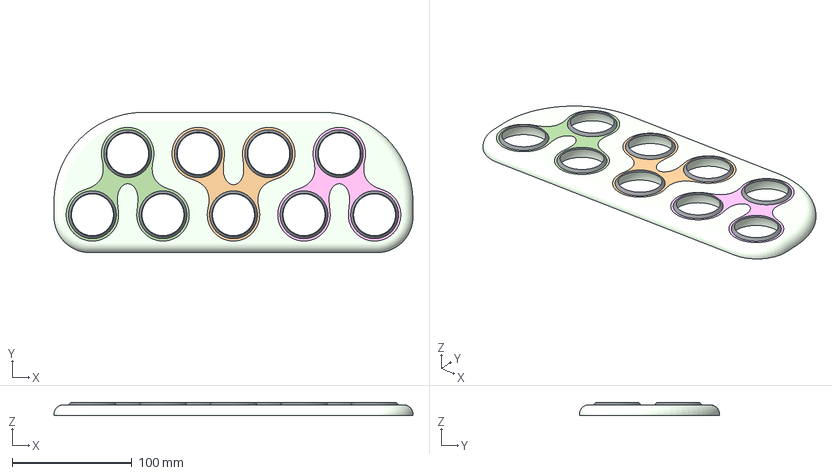
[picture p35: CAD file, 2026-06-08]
Production/3DPrint/Popn Pico 2 - Panel Combo.3mf
300.3 x 117.3 x 11.0 mm
Bubble Green
Bubble Orange
Bubble Pink
Ring x 9
Panel

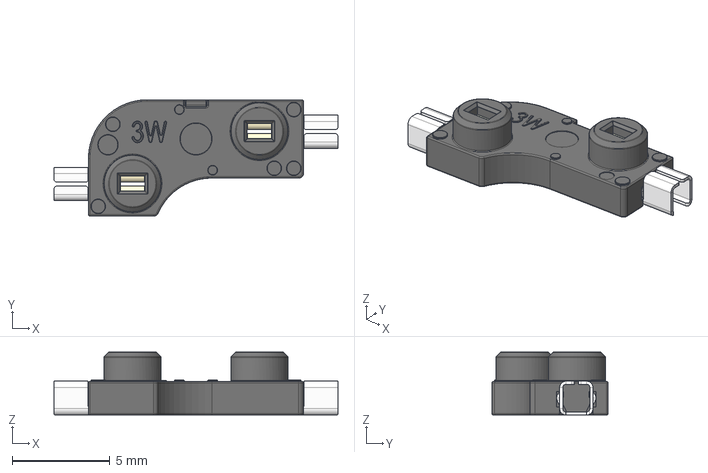
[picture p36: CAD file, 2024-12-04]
PCB/Popn2/3dmodels/SW_Hotswap_Kailh_MX.stp
14.5 x 5.95 x 3.22 mm

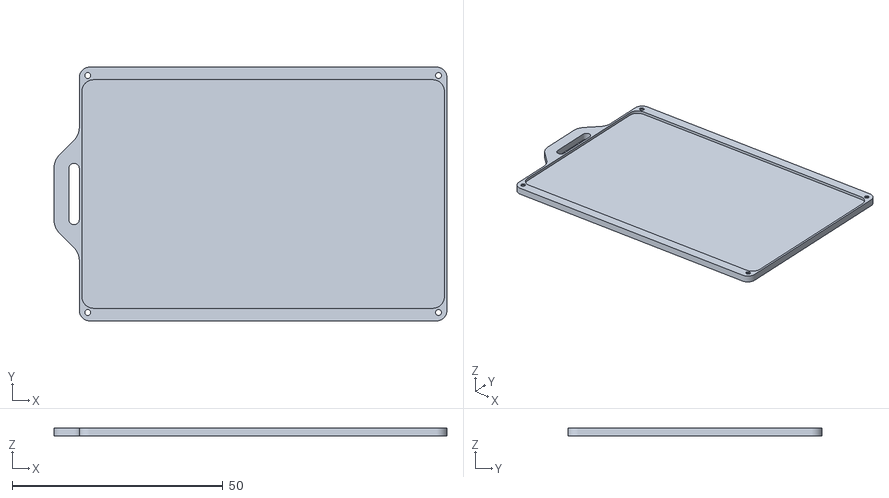
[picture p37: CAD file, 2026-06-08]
Production/3DPrint/Popn Visa - Base_Insert.stl
93.2 x 60.2 x 2.00

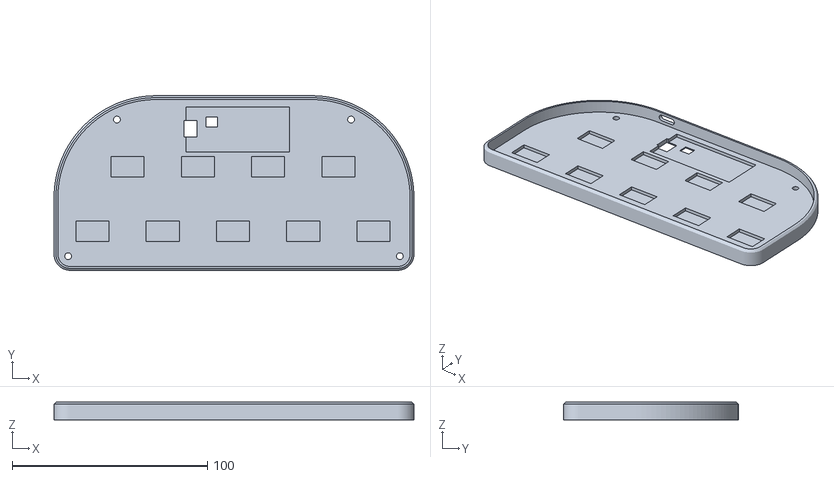
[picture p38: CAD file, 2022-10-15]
PRODUCTION/pico_popn_case.stl
184.5 x 89.5 x 9.00

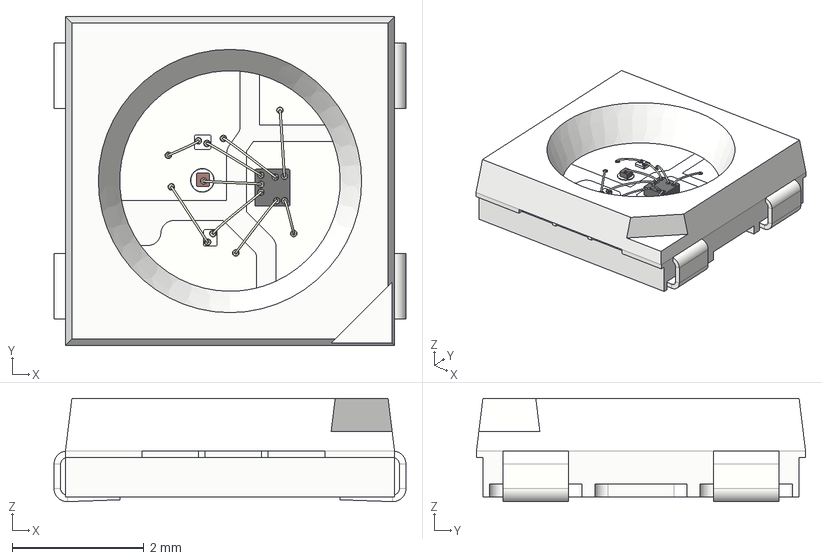
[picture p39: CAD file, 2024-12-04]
PCB/Popn2/3dmodels/WS2812B.step
5.35 x 5.00 x 1.57 mm

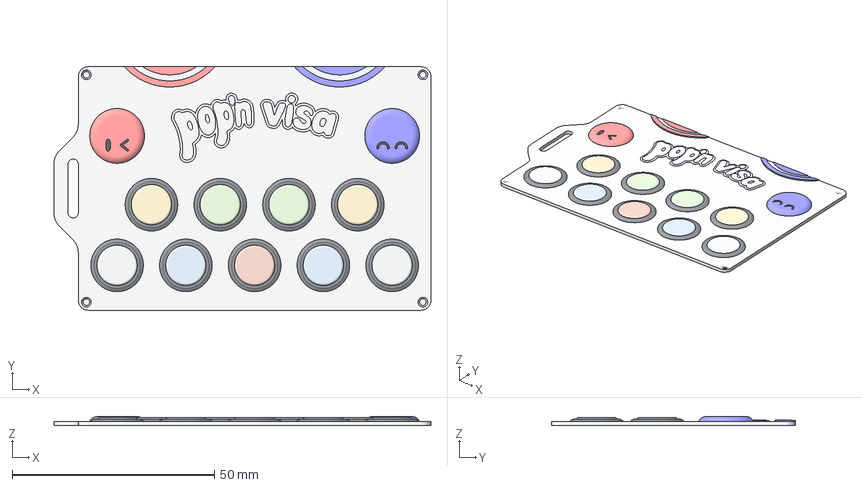
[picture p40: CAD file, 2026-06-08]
Production/3DPrint/Popn Visa - Panel_Flat.3mf
93.2 x 60.2 x 2.20 mm
Red
Panel_Flat
White x 2
Yellow x 2
Blue x 2
Green x 2
Pop-kun Red
Pop-kun Blue
Eye_L1
Eye_L2
Eye_L3
Eye_L4
Deco_L1
Deco_R1
Deco_L2
Deco_R2

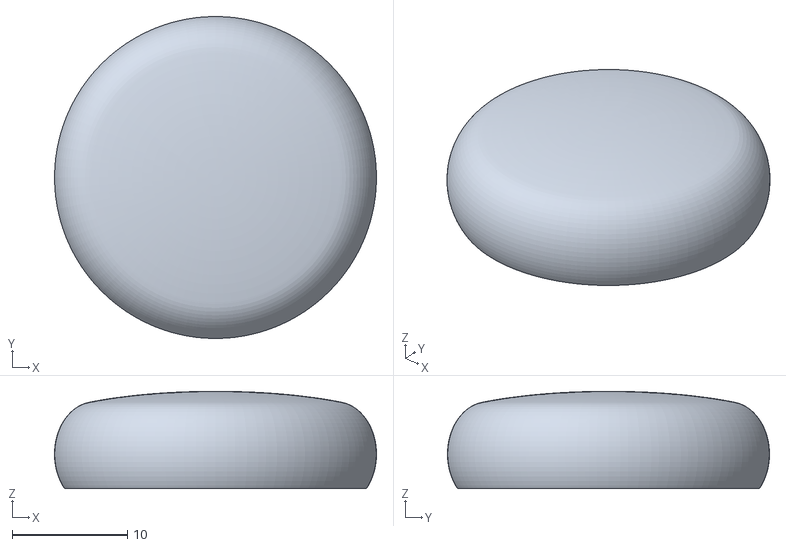
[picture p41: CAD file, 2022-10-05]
PRODUCTION/popn_keycap.stl
28.0 x 28.0 x 8.46

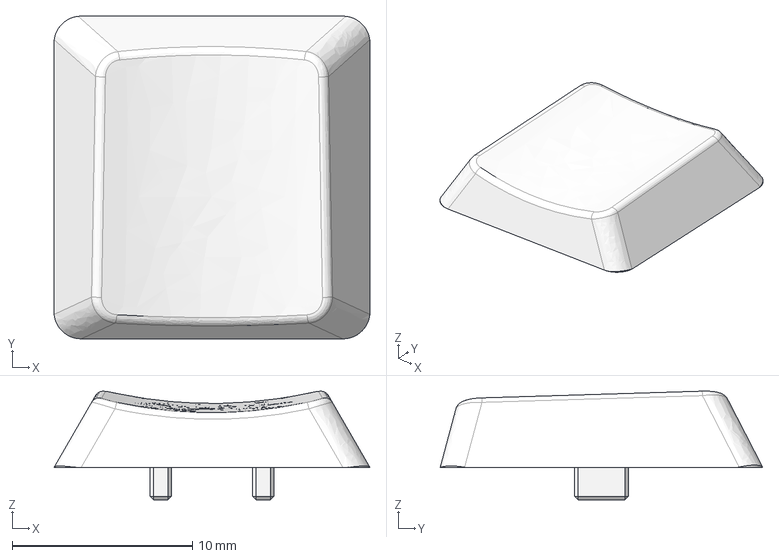
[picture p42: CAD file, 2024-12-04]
PCB/Popn2/3dmodels/Kailh LP Choc PC Keycap.step
17.5 x 17.9 x 6.03 mm

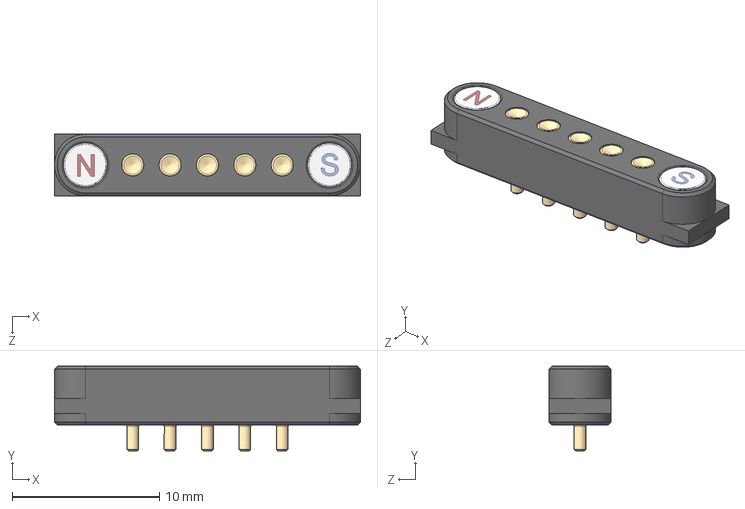
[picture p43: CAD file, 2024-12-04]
PCB/Popn2/3dmodels/Magnetic Pogo Connector 5 Pin (Type 1).STEP
20.8 x 5.75 x 4.20 mm

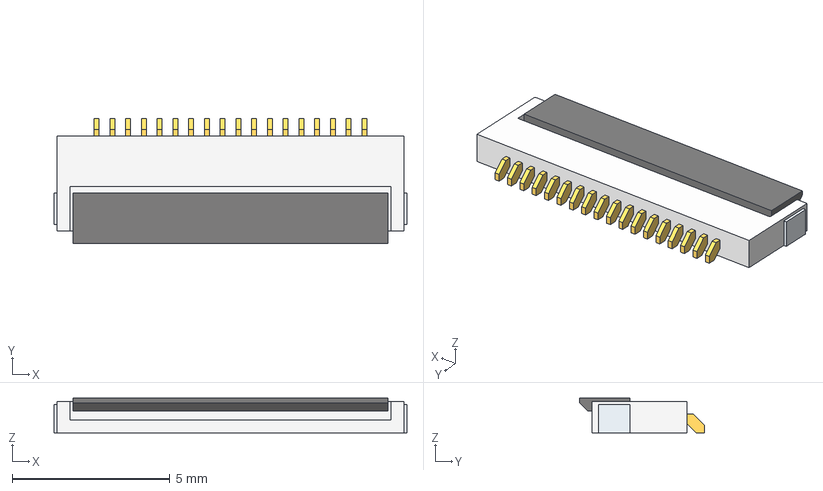
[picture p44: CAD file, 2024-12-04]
PCB/Popn2/3dmodels/FPC0.5MM1.0H18P.step
11.2 x 3.96 x 1.10 mm

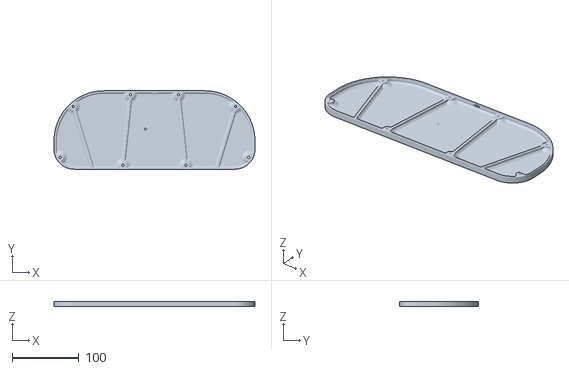
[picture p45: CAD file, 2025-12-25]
Production/3DPrint/popn_pico2_base.stl
300.3 x 117.3 x 7.60

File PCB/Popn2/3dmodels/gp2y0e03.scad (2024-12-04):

$fn=64;
translate([-5.5,-8.5]) color("darkgreen") cube([11,17,1.2]);

color("#202020") difference() {
  translate([-5,-8.4]) cube([10,4,3]);
  translate([-4,-9.3]) cube([8,4,2.4]);
}

color("#303040") difference() {
  translate([-5,-1]) cube([10,5.8,5]);
  translate([2.5,1.9,3]) cylinder(d=3.8,h=10);
  translate([-2.5,1.9,3]) cylinder(d=3.8,h=10);
}
color("#602020") {
  translate([2.5,1.9,3.2]) sphere(d=3.4);
  translate([-2.5,1.9,3.2]) sphere(d=3.4);
}
  
for (i = [-4:1:4]) {
  color("yellow") translate([i,6.5,1]) cube([0.5,1,0.6]);
}

for (i = [-4:1:4]) {
  color("silver") translate([i-0.2,-1.8,0.8]) cube([0.5,1,0.6]);
  color("silver") translate([i-0.2,4.6,0.8]) cube([0.5,1,0.6]);
}

for (i = [-4:1.3:4]) {
  color("silver") translate([i-0.3,-5,1]) cube([0.6,2,0.6]);
  color("silver") translate([i-0.6,-7,2]) cube([0.2,2,0.6]);
}

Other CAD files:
PCB/Popn2/3dmodels/iidx_keycap_main_step.stp
Production/3DPrint/Popn Visa - Base.stl
Production/3DPrint/Popn Visa - Panel.3mf
PCB/Popn2/3dmodels/SKSTAAE010.stp
PCB/Popn2/3dmodels/keypad_lgp.scad
Gen1Archive/BUTTON/popn_keycap.scad
Gen1Archive/CASE/pico_popn_case.scad
Gen1Archive/CASE/screw_spacer.scad
Gen1Archive/PCB/3dmodels/J 2835.step
Gen1Archive/PCB/3dmodels/Tact Switch 4.5mm SMT.step
Gen1Archive/PCB/3dmodels/User Library-PTS645SL95SMTR92-LFS.STEP
Gen1Archive/PCB/3dmodels/User Library-WS2812-4020.step
Gen1Archive/PRODUCTION/screw_spacer.stl
PCB/3dmodels/User Library-PTS645SL95SMTR92-LFS.STEP
PCB/3dmodels/User Library-WS2812-4020.step
PCB/Popn2/3dmodels/530470310.stp
PCB/Popn2/3dmodels/8002A.step
PCB/Popn2/3dmodels/Button Cap.step
PCB/Popn2/3dmodels/EVQ-P1D05M.stp
PCB/Popn2/3dmodels/Geki_Slider.step
PCB/Popn2/3dmodels/J 2835.step
PCB/Popn2/3dmodels/Kailh Polia.step
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

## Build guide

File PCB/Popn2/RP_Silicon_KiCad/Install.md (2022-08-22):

# Install KiCad libraries

## Manage Symbol Libraries

Accessed from the Preferences menu, add a new line with the +, give it a name and use the folder icon to point to the directory/folder where you have KiCadLibraries.

Manage Symbol Libraries screen shot


## Manage Footprint Libraries

Ditto! Accessed from the Preferences menu, add a new line with the +, give it a name and use the folder icon to point to the directory/folder where you have KiCadLibraries.

Manage Footprint Libraries screen shot


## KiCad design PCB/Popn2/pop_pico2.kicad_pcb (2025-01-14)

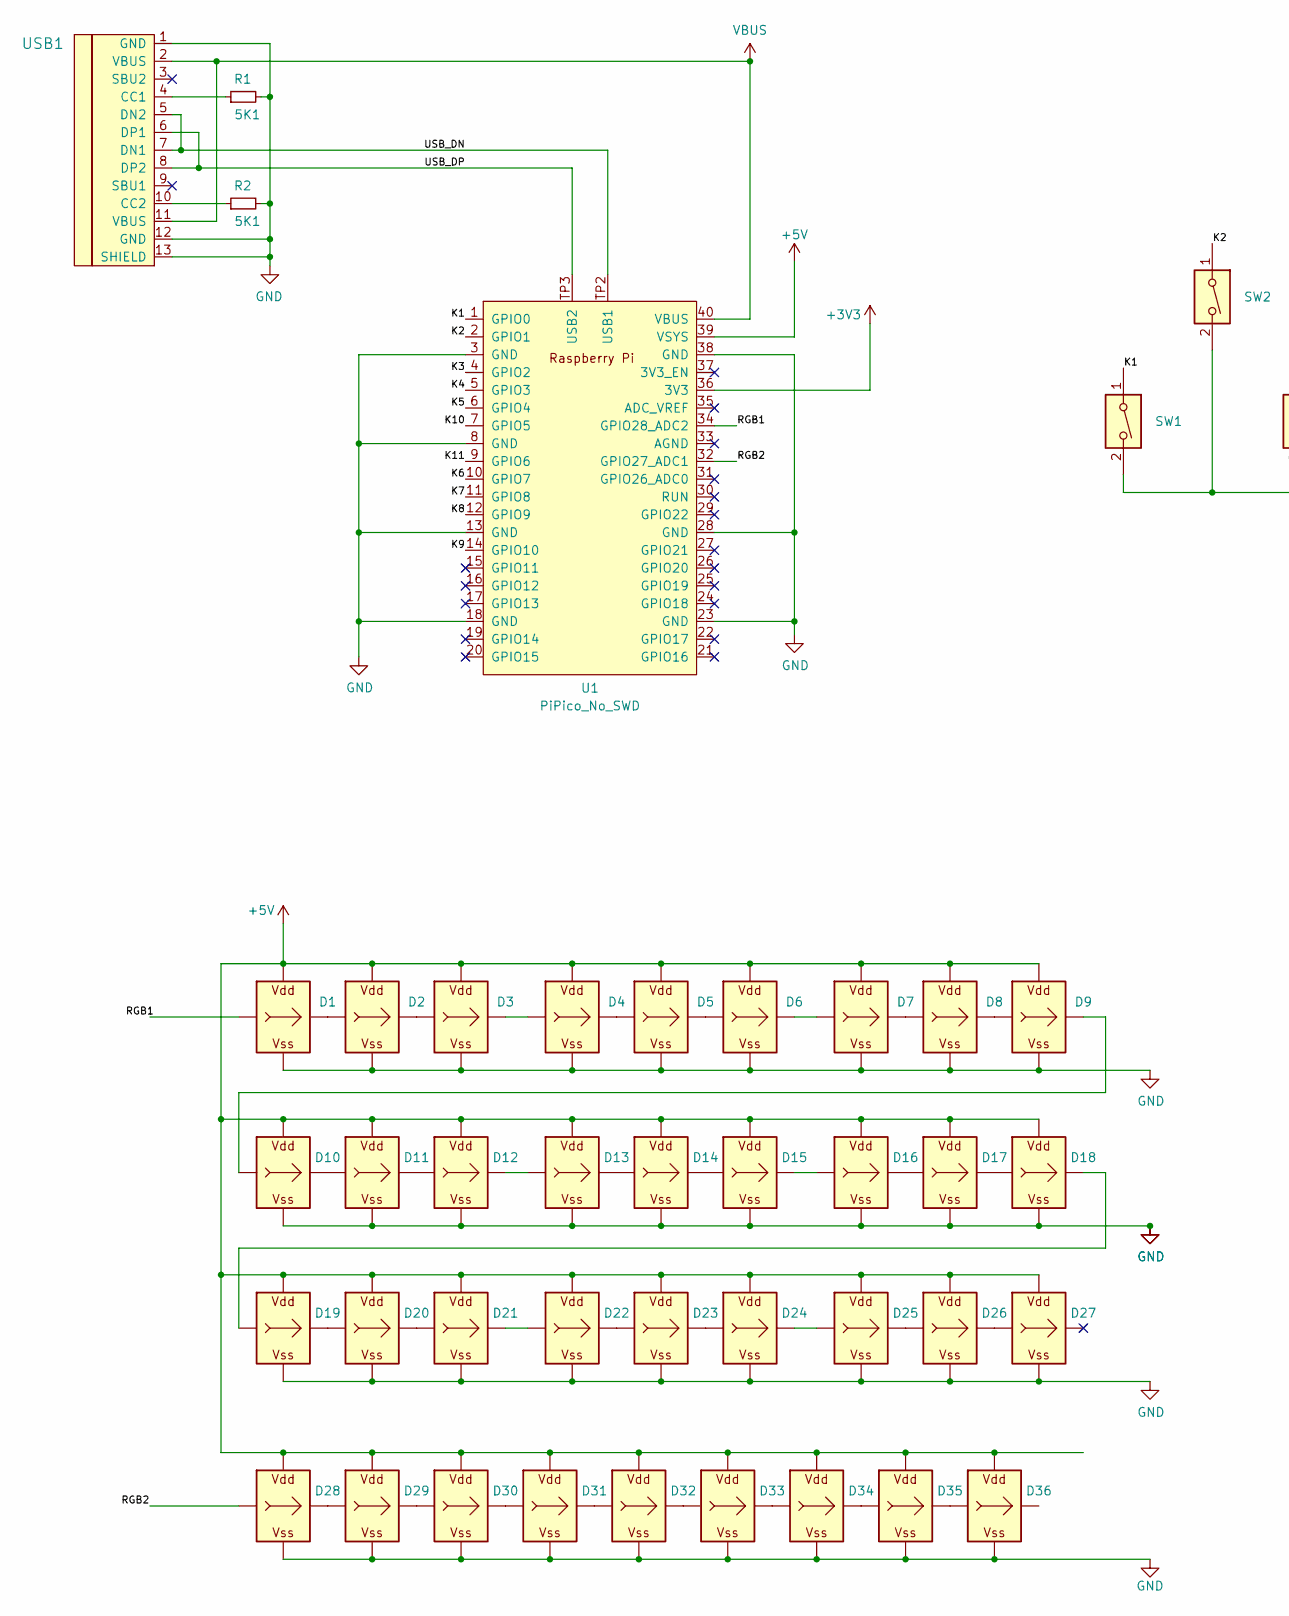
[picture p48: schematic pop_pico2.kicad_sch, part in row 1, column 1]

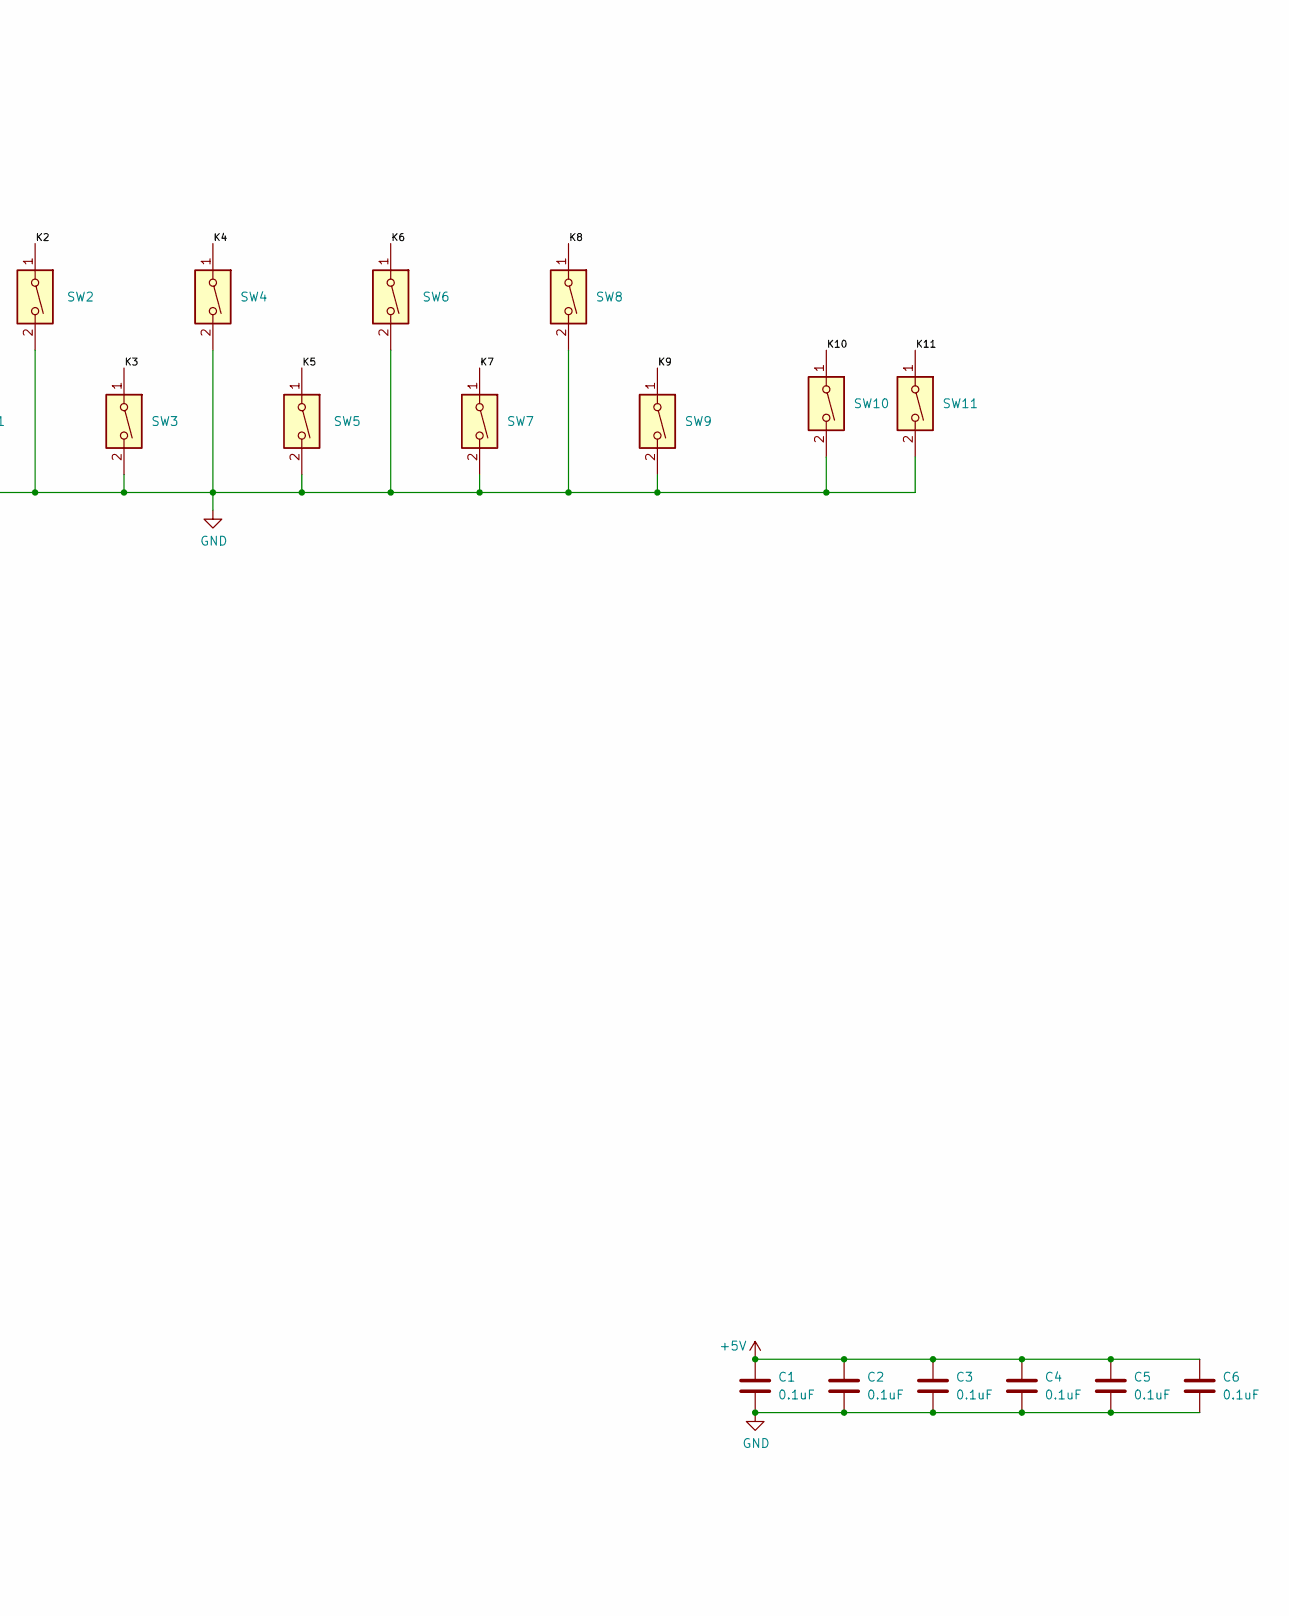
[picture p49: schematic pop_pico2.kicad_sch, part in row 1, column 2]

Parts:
C1, C2, C3, C4, C5, C6: 0.1uF; C_0603_1608Metric_Pad1.08x0.95mm_HandSolder
D1, D2, D3, D4, D5, D6, D7, D8, D9, D10, D11, D12, D13, D14, D15, D16, D17, D18, D19, D20, D21, D22, D23, D24, D25, D26, D27: WS2812B_Unified; WS2812B-2835
D28, D29, D30, D31, D32, D33, D34, D35, D36: WS2812B_Unified; WS2812B-4020
R1, R2: 5K1; R_0603_1608Metric_Pad0.98x0.95mm_HandSolder; LCSC C23186
SW1, SW2, SW3, SW4, SW5, SW6, SW7, SW8, SW9: SW_DIP_x01; SW_Choc_V1V2_Cherry_MX_LED
SW10, SW11: SW_DIP_x01; Omron_B3F-315x_Angled
U1: PiPico_No_SWD; RPi_Pico_SMD_Pins_No_SWD
USB1: U262-161N-4BVC11; HRO-TYPE-C-31-M-12-Assembly; LCSC C319148

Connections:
+3V3: U1.36 (3V3)
+5V: C1.1, C2.1, C3.1, C4.1, C5.1, C6.1, D1.V (VDD), D2.V (VDD), D3.V (VDD), D4.V (VDD), D5.V (VDD), D6.V (VDD), D7.V (VDD), D8.V (VDD), D9.V (VDD), D10.V (VDD), D11.V (VDD), D12.V (VDD), D13.V (VDD), D14.V (VDD), D15.V (VDD), D16.V (VDD), D17.V (VDD), D18.V (VDD), D19.V (VDD), D20.V (VDD), D21.V (VDD), D22.V (VDD), D23.V (VDD), D24.V (VDD), D25.V (VDD), D26.V (VDD), D27.V (VDD), D28.V (VDD), D29.V (VDD), D30.V (VDD), D31.V (VDD), D32.V (VDD), D33.V (VDD), D34.V (VDD), D35.V (VDD), D36.V (VDD), U1.39 (VSYS)
/K1: SW1.1, U1.1 (GPIO0)
/K2: SW2.1, U1.2 (GPIO1)
/K3: SW3.1, U1.4 (GPIO2)
/K4: SW4.1, U1.5 (GPIO3)
/K5: SW5.1, U1.6 (GPIO4)
/K6: SW6.1, U1.10 (GPIO7)
/K7: SW7.1, U1.11 (GPIO8)
/K8: SW8.1, U1.12 (GPIO9)
/K9: SW9.1, U1.14 (GPIO10)
/K10: SW10.1, U1.7 (GPIO5)
/K11: SW11.1, U1.9 (GPIO6)
/RGB1: D1.I (In), U1.34 (GPIO28_ADC2)
/RGB2: D28.I (In), U1.32 (GPIO27_ADC1)
/USB_DN: U1.TP2 (USB1), USB1.5 (DN2), USB1.7 (DN1)
/USB_DP: U1.TP3 (USB2), USB1.6 (DP1), USB1.8 (DP2)
GND: C1.2, C2.2, C3.2, C4.2, C5.2, C6.2, D1.G (VSS), D2.G (VSS), D3.G (VSS), D4.G (VSS), D5.G (VSS), D6.G (VSS), D7.G (VSS), D8.G (VSS), D9.G (VSS), D10.G (VSS), D11.G (VSS), D12.G (VSS), D13.G (VSS), D14.G (VSS), D15.G (VSS), D16.G (VSS), D17.G (VSS), D18.G (VSS), D19.G (VSS), D20.G (VSS), D21.G (VSS), D22.G (VSS), D23.G (VSS), D24.G (VSS), D25.G (VSS), D26.G (VSS), D27.G (VSS), D28.G (VSS), D29.G (VSS), D30.G (VSS), D31.G (VSS), D32.G (VSS), D33.G (VSS), D34.G (VSS), D35.G (VSS), D36.G (VSS), R1.2, R2.2, SW1.2, SW2.2, SW3.2, SW4.2, SW5.2, SW6.2, SW7.2, SW8.2, SW9.2, SW10.2, SW11.2, U1.3 (GND), U1.8 (GND), U1.13 (GND), U1.18 (GND), U1.23 (GND), U1.28 (GND), U1.38 (GND), USB1.1 (GND), USB1.12 (GND), USB1.13 (SHIELD)
unnamed: D1.O (Out), D2.I (In)
unnamed: D2.O (Out), D3.I (In)
unnamed: D3.O (Out), D4.I (In)
unnamed: D4.O (Out), D5.I (In)
unnamed: D5.O (Out), D6.I (In)
unnamed: D6.O (Out), D7.I (In)
unnamed: D7.O (Out), D8.I (In)
unnamed: D8.O (Out), D9.I (In)
unnamed: D9.O (Out), D10.I (In)
unnamed: D10.O (Out), D11.I (In)
unnamed: D11.O (Out), D12.I (In)
unnamed: D12.O (Out), D13.I (In)
unnamed: D13.O (Out), D14.I (In)
unnamed: D14.O (Out), D15.I (In)
unnamed: D15.O (Out), D16.I (In)
unnamed: D16.O (Out), D17.I (In)
unnamed: D17.O (Out), D18.I (In)
unnamed: D18.O (Out), D19.I (In)
unnamed: D19.O (Out), D20.I (In)
unnamed: D20.O (Out), D21.I (In)
unnamed: D21.O (Out), D22.I (In)
unnamed: D22.O (Out), D23.I (In)
unnamed: D23.O (Out), D24.I (In)
unnamed: D24.O (Out), D25.I (In)
unnamed: D25.O (Out), D26.I (In)
unnamed: D26.O (Out), D27.I (In)
unnamed: D28.O (Out), D29.I (In)
unnamed: D29.O (Out), D30.I (In)
unnamed: D30.O (Out), D31.I (In)
unnamed: D31.O (Out), D32.I (In)
unnamed: D32.O (Out), D33.I (In)
unnamed: D33.O (Out), D34.I (In)
unnamed: D34.O (Out), D35.I (In)
unnamed: D35.O (Out), D36.I (In)
unnamed: R1.1, USB1.4 (CC1)
unnamed: R2.1, USB1.10 (CC2)
VBUS: U1.40 (VBUS), USB1.2 (VBUS), USB1.11 (VBUS)

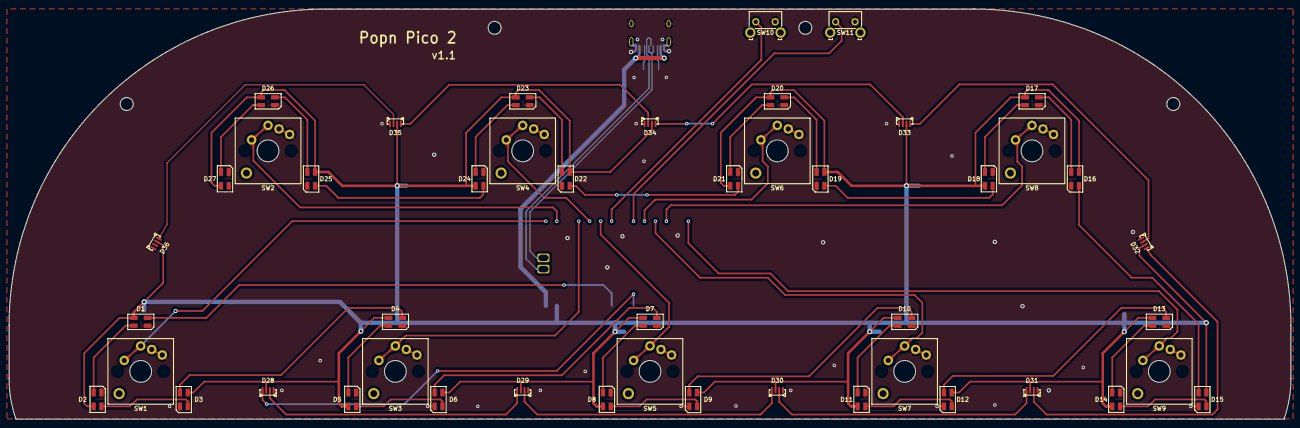
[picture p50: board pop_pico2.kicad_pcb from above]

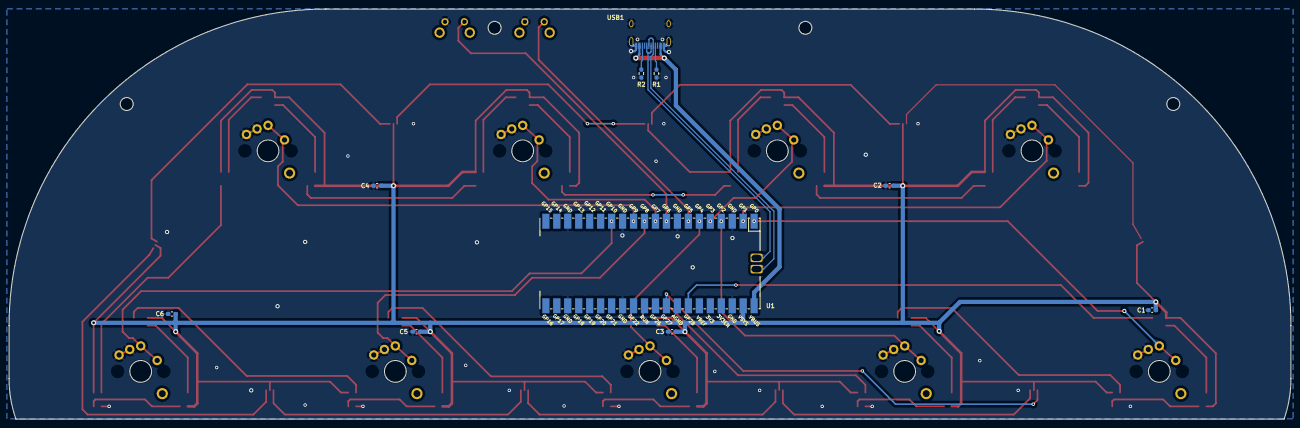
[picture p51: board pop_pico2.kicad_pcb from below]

Board: 2 copper layers, 297.0 x 95.0 mm, 57 parts (10 on the bottom side), 54 nets.

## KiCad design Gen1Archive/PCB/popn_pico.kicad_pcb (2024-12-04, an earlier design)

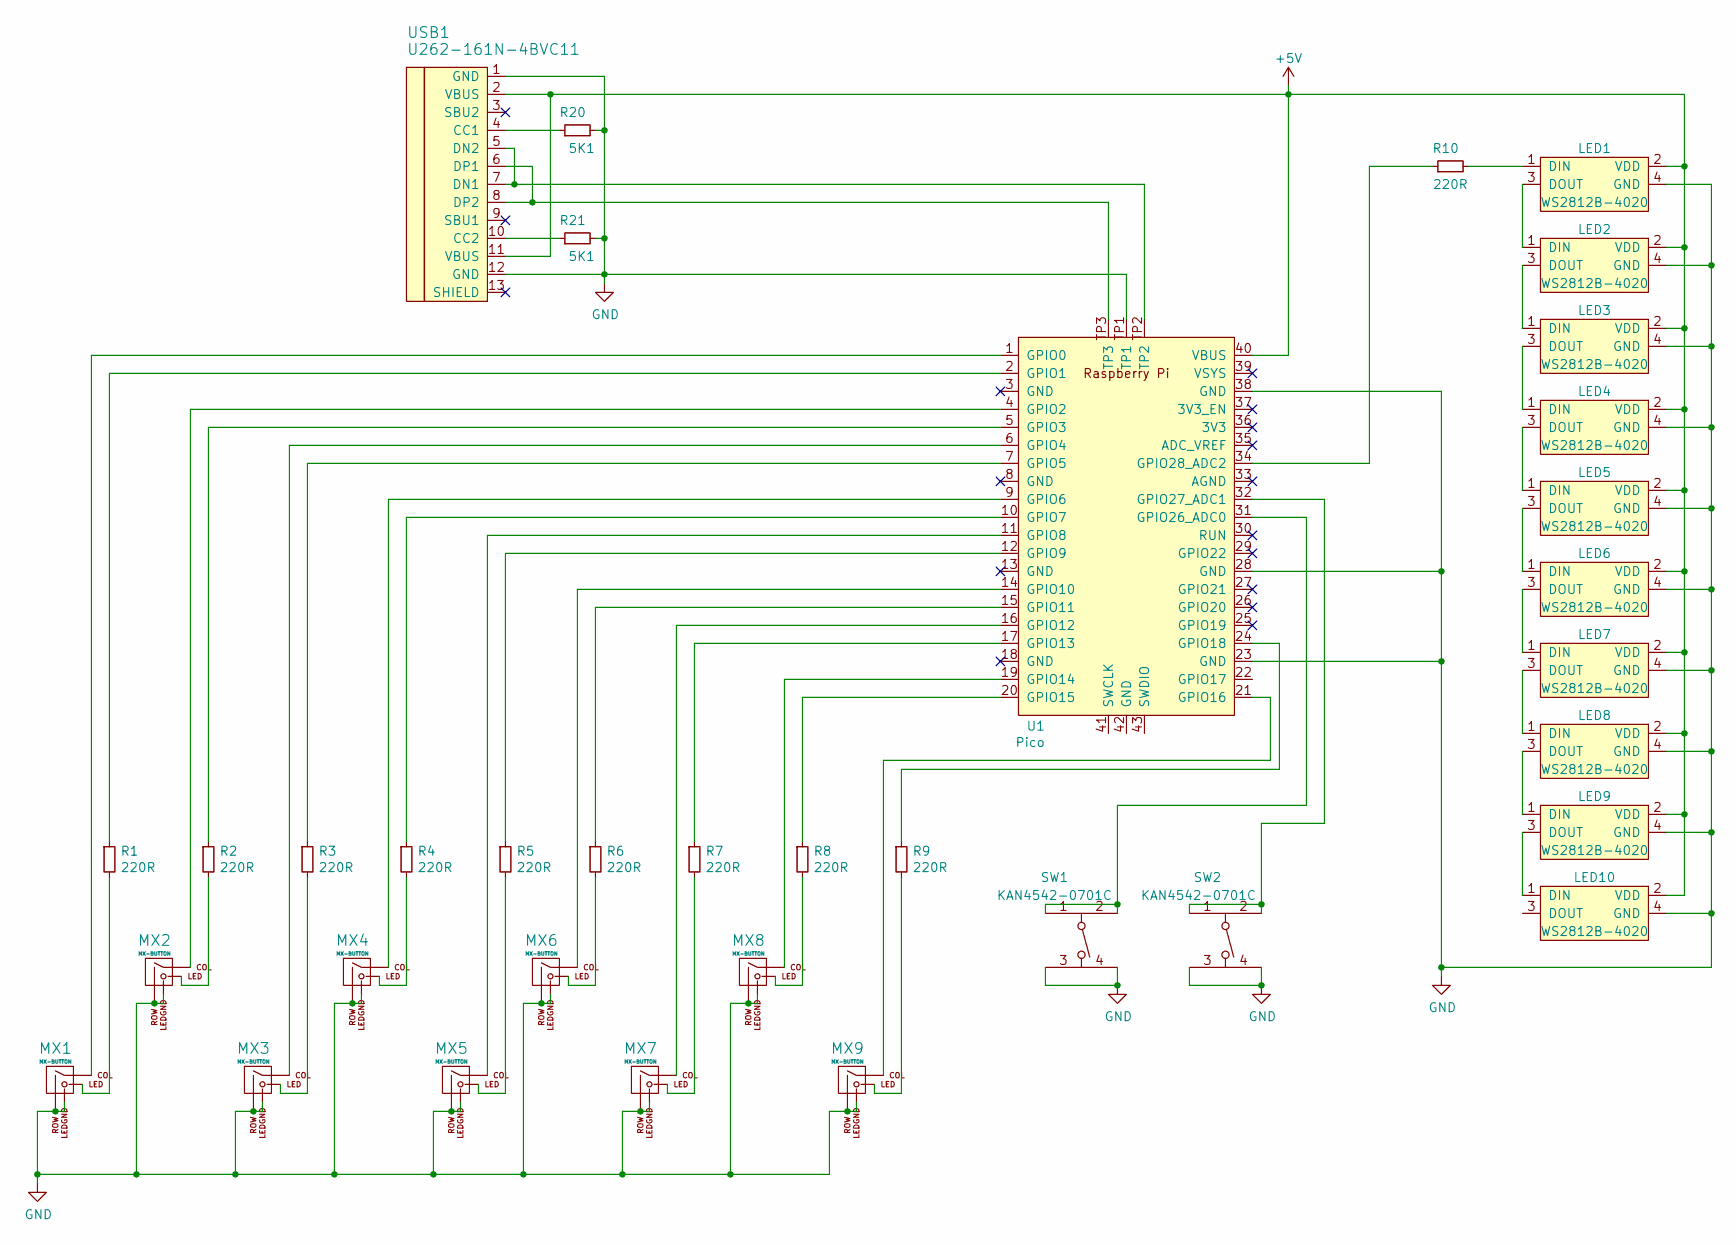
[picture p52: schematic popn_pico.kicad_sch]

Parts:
LED1, LED2, LED3, LED4, LED5, LED6, LED7, LED8, LED9, LED10: WS2812B-4020
MX1: MX-BUTTON; MXOnly-Popn_Button-Hotswap-LED; LCSC C440444
MX2, MX3, MX4, MX5: MX-BUTTON; MXOnly-Popn_Button-Hotswap-LED; LCSC C26545
MX6, MX7, MX8, MX9: MX-BUTTON; MXOnly-Popn_Button-Hotswap-LED; LCSC C440441
R1, R2, R3, R4, R5, R6, R7, R8, R9, R10: 220R; R_0603_1608Metric; LCSC C22962
R20, R21: 5K1; R_0603_1608Metric; LCSC C23186
SW1, SW2: KAN4542-0701C; LCSC C231726
U1: Pico; RPi_Pico_SMD
USB1: U262-161N-4BVC11; HRO-TYPE-C-31-M-12-Assembly; LCSC C319148

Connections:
+5V: LED1.2 (VDD), LED2.2 (VDD), LED3.2 (VDD), LED4.2 (VDD), LED5.2 (VDD), LED6.2 (VDD), LED7.2 (VDD), LED8.2 (VDD), LED9.2 (VDD), LED10.2 (VDD), U1.40 (VBUS), USB1.2 (VBUS), USB1.11 (VBUS)
GND: LED1.4 (GND), LED2.4 (GND), LED3.4 (GND), LED4.4 (GND), LED5.4 (GND), LED6.4 (GND), LED7.4 (GND), LED8.4 (GND), LED9.4 (GND), LED10.4 (GND), MX1.2 (ROW), MX1.4 (LEDGND), MX2.2 (ROW), MX2.4 (LEDGND), MX3.2 (ROW), MX3.4 (LEDGND), MX4.2 (ROW), MX4.4 (LEDGND), MX5.2 (ROW), MX5.4 (LEDGND), MX6.2 (ROW), MX6.4 (LEDGND), MX7.2 (ROW), MX7.4 (LEDGND), MX8.2 (ROW), MX8.4 (LEDGND), MX9.2 (ROW), MX9.4 (LEDGND), R20.2, R21.2, SW1.3, SW1.4, SW2.3, SW2.4, U1.23 (GND), U1.28 (GND), U1.38 (GND), U1.TP1, USB1.1 (GND), USB1.12 (GND)
unnamed: LED1.1 (DIN), R10.2
unnamed: LED1.3 (DOUT), LED2.1 (DIN)
unnamed: LED2.3 (DOUT), LED3.1 (DIN)
unnamed: LED3.3 (DOUT), LED4.1 (DIN)
unnamed: LED4.3 (DOUT), LED5.1 (DIN)
unnamed: LED5.3 (DOUT), LED6.1 (DIN)
unnamed: LED6.3 (DOUT), LED7.1 (DIN)
unnamed: LED7.3 (DOUT), LED8.1 (DIN)
unnamed: LED8.3 (DOUT), LED9.1 (DIN)
unnamed: LED9.3 (DOUT), LED10.1 (DIN)
unnamed: MX1.1 (COL), U1.1 (GPIO0)
unnamed: MX1.3 (LED), R1.2
unnamed: MX2.1 (COL), U1.4 (GPIO2)
unnamed: MX2.3 (LED), R2.2
unnamed: MX3.1 (COL), U1.6 (GPIO4)
unnamed: MX3.3 (LED), R3.2
unnamed: MX4.1 (COL), U1.9 (GPIO6)
unnamed: MX4.3 (LED), R4.2
unnamed: MX5.1 (COL), U1.11 (GPIO8)
unnamed: MX5.3 (LED), R5.2
unnamed: MX6.1 (COL), U1.14 (GPIO10)
unnamed: MX6.3 (LED), R6.2
unnamed: MX7.1 (COL), U1.16 (GPIO12)
unnamed: MX7.3 (LED), R7.2
unnamed: MX8.1 (COL), U1.19 (GPIO14)
unnamed: MX8.3 (LED), R8.2
unnamed: MX9.1 (COL), U1.21 (GPIO16)
unnamed: MX9.3 (LED), R9.2
unnamed: R1.1, U1.2 (GPIO1)
unnamed: R2.1, U1.5 (GPIO3)
unnamed: R3.1, U1.7 (GPIO5)
unnamed: R4.1, U1.10 (GPIO7)
unnamed: R5.1, U1.12 (GPIO9)
unnamed: R6.1, U1.15 (GPIO11)
unnamed: R7.1, U1.17 (GPIO13)
unnamed: R8.1, U1.20 (GPIO15)
unnamed: R10.1, U1.34 (GPIO28_ADC2)
unnamed: R20.1, USB1.4 (CC1)
unnamed: R21.1, USB1.10 (CC2)
unnamed: SW1.1, SW1.2, U1.31 (GPIO26_ADC0)
unnamed: SW2.1, SW2.2, U1.32 (GPIO27_ADC1)
unnamed: R9.1, U1.24 (GPIO18)
unnamed: U1.TP2, USB1.5 (DN2), USB1.7 (DN1)
unnamed: U1.TP3, USB1.6 (DP1), USB1.8 (DP2)

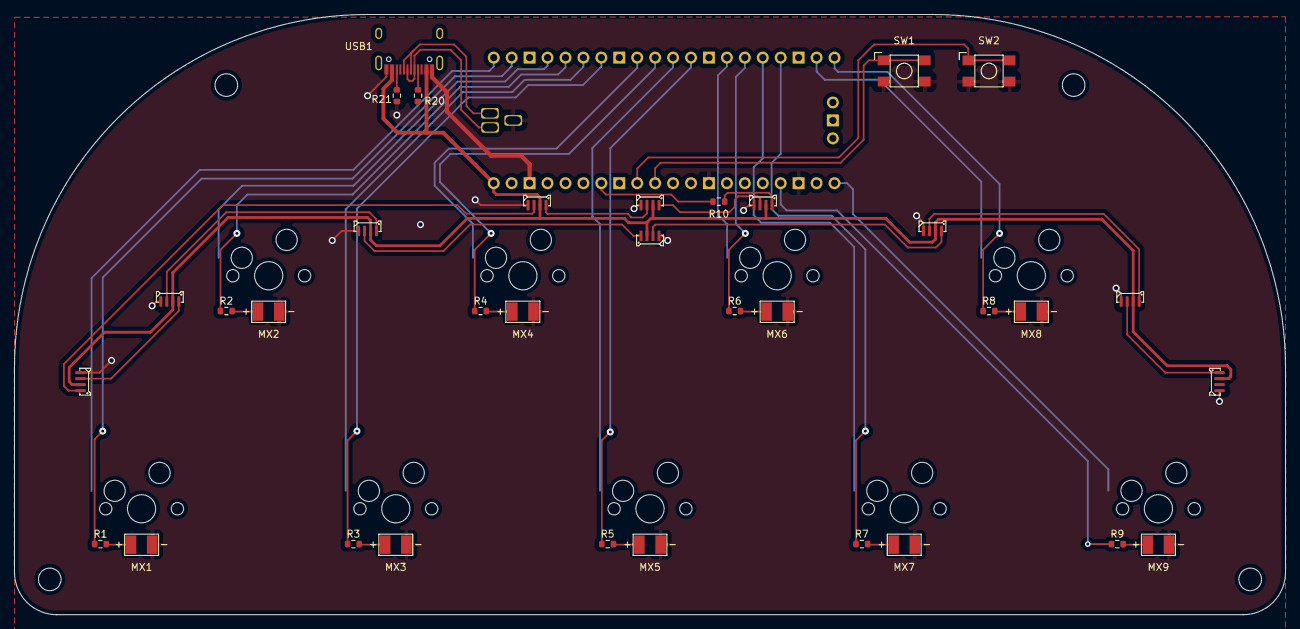
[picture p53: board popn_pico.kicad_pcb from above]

Board: 2 copper layers, 180.0 x 85.0 mm, 35 parts (1 on the bottom side), 46 nets.

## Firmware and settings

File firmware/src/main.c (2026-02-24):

/*
 * Controller Main
 * WHowe <github.com/whowechina>
 */

#include <stdlib.h>
#include <stdint.h>
#include <stdbool.h>

#include "pico/stdio.h"
#include "pico/stdlib.h"
#include "bsp/board.h"
#include "pico/multicore.h"
#include "pico/bootrom.h"

#include "hardware/clocks.h"
#include "hardware/gpio.h"
#include "hardware/sync.h"
#include "hardware/structs/ioqspi.h"
#include "hardware/structs/sio.h"

#include "tusb.h"
#include "usb_descriptors.h"

#include "board_defs.h"

#include "save.h"
#include "config.h"
#include "cli.h"
#include "commands.h"

#include "light.h"
#include "button.h"


typedef struct {
    uint8_t h;
    uint8_t s;
    uint8_t v;
} hsv_t;

static struct {
    hsv_t on[9];
    hsv_t off[9];
} main_theme = {
    .on = {
        { 0, 0, 255 },
        { HUE_YELLOW, 240, 255 },
        { HUE_GREEN, 240, 255 },
        { HUE_BLUE, 240, 255 },
        { HUE_RED, 240, 255 },
        { HUE_BLUE, 240, 255 },
        { HUE_GREEN, 240, 255 },
        { HUE_YELLOW, 240, 255 },
        { 0, 0, 255 },
    },
    .off = {
        { 0, 0, 128 },
        { HUE_YELLOW, 255, 80 },
        { HUE_GREEN, 255, 80 },
        { HUE_BLUE, 255, 80 },
        { HUE_RED, 255, 80 },
        { HUE_BLUE, 255, 80 },
        { HUE_GREEN, 255, 80 },
        { HUE_YELLOW, 255, 80 },
        { 0, 0, 128 },
    }
};

static uint32_t hsv2rgb(hsv_t hsv)
{
    return rgb32_from_hsv(hsv.h, hsv.s, hsv.v);
}

static void light_render()
{
    uint32_t phase = time_us_32() >> 16;

    for (int i = 0; i < 9; i ++) {
//        uint32_t color = rgb32_from_hsv(phase + i * 27, 255, 128);
        uint32_t color = hsv2rgb(main_theme.off[i]);
        light_set_button(i, color, false);
    }

    uint16_t button = button_read();
    for (int i = 0; i < 9; i++) {
        if (button & (1 << i)) {
//            light_set_button(i, WHITE, false);
            light_set_button(i, hsv2rgb(main_theme.on[i]), false);
        }
    }

    for (int i = 0; i < 9; i++) {
        uint32_t color = rgb32_from_hsv(phase + i * 25, 255, 160);
        light_set_cab(i, color, false);
    }
}

static void run_lights()
{
    static uint64_t next_frame = 0;
    uint64_t now = time_us_64();
    if (now < next_frame) {
        return;
    }
    next_frame = now + 1000000 / 120; // 120Hz

    light_render();
}

static mutex_t core1_io_lock;
static void core1_loop()
{
    while (1) {
        if (mutex_try_enter(&core1_io_lock, NULL)) {
            run_lights();
            light_update();
            mutex_exit(&core1_io_lock);
        }
        cli_fps_count(1);
        sleep_us(700);
    }
}

struct __attribute__((packed)) {
    uint16_t buttons;
} hid_joy, hid_joy_sent = {0};

static void hid_update()
{
    static uint64_t last_report_time = 0;

    if (!tud_hid_ready()) {
        return;
    }

    uint64_t now = time_us_64();
    hid_joy.buttons = button_read();
    if ((memcmp(&hid_joy, &hid_joy_sent, sizeof(hid_joy)) == 0) &&
        (now - last_report_time < 10000)) {
        return;
    }
    last_report_time = now;
    if (tud_hid_report(REPORT_ID_JOYSTICK, &hid_joy, sizeof(hid_joy))) {
        hid_joy_sent = hid_joy;
    }
}

static void core0_loop()
{
    uint64_t next_frame = 0;

    while(1) {
        tud_task();

        cli_run();

        save_loop();
        cli_fps_count(0);

        button_update();

        hid_update();

        sleep_until(next_frame);
        next_frame += 1001;
    }
}

/* if certain key pressed when booting, enter update mode */
static void update_check()
{
    const uint8_t pins[] = BUTTON_DEF;
    int pressed = 0;
    for (int i = 0; i < count_of(pins); i++) {
        uint8_t gpio = pins[i];
        gpio_init(gpio);
        gpio_set_function(gpio, GPIO_FUNC_SIO);
        gpio_set_dir(gpio, GPIO_IN);
        gpio_pull_up(gpio);
        sleep_ms(1);
        if (!gpio_get(gpio)) {
            pressed++;
        }
    }

    if (pressed >= 3) {
        sleep_ms(100);
        reset_usb_boot(0, 2);
        return;
    }
}

void init()
{
    sleep_ms(50);
    set_sys_clock_khz(150000, true);

    board_init();

    update_check();

    tusb_init();
    stdio_init_all();

    config_init();
    mutex_init(&core1_io_lock);
    save_init(0xca44caac, &core1_io_lock);

    light_init();
    button_init();

    cli_init("popn_pico>", "\n   << Popn Pico 2 Controller >>\n"
                            " https://github.com/whowechina\n\n");
    
    commands_init();
}

int main(void)
{
    init();
    multicore_launch_core1(core1_loop);
    core0_loop();
    return 0;
}

// Invoked when received GET_REPORT control request
// Application must fill buffer report's content and return its length.
// Return zero will cause the stack to STALL request
uint16_t tud_hid_get_report_cb(uint8_t itf, uint8_t report_id,
                               hid_report_type_t report_type, uint8_t *buffer,
                               uint16_t reqlen)
{
    printf("Get from USB %d-%d\n", report_id, report_type);
    return 0;
}

// Invoked when received SET_REPORT control request or
// received data on OUT endpoint ( Report ID = 0, Type = 0 )
void tud_hid_set_report_cb(uint8_t itf, uint8_t report_id,
                           hid_report_type_t report_type, uint8_t const *buffer,
                           uint16_t bufsize)
{
    if (report_id == REPORT_ID_LIGHTS) {
        if (bufsize < 12) {
            return;
        }
        for (int i = 0; i < 9; i++) {
            if (buffer[i]) {
                light_set_button(i, hsv2rgb(main_theme.on[i]), true);
            } else {
                light_set_button(i, hsv2rgb(main_theme.off[i]), true);
            }
        }
        uint32_t color = rgb32(buffer[9], buffer[10], buffer[11], false);
        light_set_cab_all(color, true);
    }
}

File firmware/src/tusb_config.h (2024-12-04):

/*
 * The MIT License (MIT)
 *
 * Copyright (c) 2019 Ha Thach (tinyusb.org)
 *
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
 */

#ifndef _TUSB_CONFIG_H_
#define _TUSB_CONFIG_H_

#ifdef __cplusplus
extern "C" {
#endif

//--------------------------------------------------------------------
// COMMON CONFIGURATION
//--------------------------------------------------------------------

// defined by board.mk
#ifndef CFG_TUSB_MCU
#error CFG_TUSB_MCU must be defined
#endif

// RHPort number used for device can be defined by board.mk, default to port 0
#ifndef BOARD_DEVICE_RHPORT_NUM
#define BOARD_DEVICE_RHPORT_NUM 0
#endif

// RHPort max operational speed can defined by board.mk
// Default to Highspeed for MCU with internal HighSpeed PHY (can be port
// specific), otherwise FullSpeed
#ifndef BOARD_DEVICE_RHPORT_SPEED
#if (CFG_TUSB_MCU == OPT_MCU_LPC18XX || CFG_TUSB_MCU == OPT_MCU_LPC43XX ||   \
     CFG_TUSB_MCU == OPT_MCU_MIMXRT10XX || CFG_TUSB_MCU == OPT_MCU_NUC505 || \
     CFG_TUSB_MCU == OPT_MCU_CXD56)
#define BOARD_DEVICE_RHPORT_SPEED OPT_MODE_HIGH_SPEED
#else
#define BOARD_DEVICE_RHPORT_SPEED OPT_MODE_FULL_SPEED
#endif
#endif

// Device mode with rhport and speed defined by board.mk
#if BOARD_DEVICE_RHPORT_NUM == 0
#define CFG_TUSB_RHPORT0_MODE (OPT_MODE_DEVICE | BOARD_DEVICE_RHPORT_SPEED)
#elif BOARD_DEVICE_RHPORT_NUM == 1
#define CFG_TUSB_RHPORT1_MODE (OPT_MODE_DEVICE | BOARD_DEVICE_RHPORT_SPEED)
#else
#error "Incorrect RHPort configuration"
#endif

#ifndef CFG_TUSB_OS
#define CFG_TUSB_OS OPT_OS_NONE
#endif

// CFG_TUSB_DEBUG is defined by compiler in DEBUG build
// #define CFG_TUSB_DEBUG           0

/* USB DMA on some MCUs can only access a specific SRAM region with restriction
 * on alignment. Tinyusb use follows macros to declare transferring memory so
 * that they can be put into those specific section. e.g
 * - CFG_TUSB_MEM SECTION : __attribute__ (( section(".usb_ram") ))
 * - CFG_TUSB_MEM_ALIGN   : __attribute__ ((aligned(4)))
 */
#ifndef CFG_TUSB_MEM_SECTION
#define CFG_TUSB_MEM_SECTION
#endif

#ifndef CFG_TUSB_MEM_ALIGN
#define CFG_TUSB_MEM_ALIGN __attribute__((aligned(4)))
#endif

//--------------------------------------------------------------------
// DEVICE CONFIGURATION
//--------------------------------------------------------------------

#ifndef CFG_TUD_ENDPOINT0_SIZE
#define CFG_TUD_ENDPOINT0_SIZE 64
#endif

//------------- CLASS -------------//
#define CFG_TUD_HID 1
#define CFG_TUD_CDC 1
#define CFG_TUD_MSC 0
#define CFG_TUD_MIDI 0
#define CFG_TUD_VENDOR 0

// HID buffer size Should be sufficient to hold ID (if any) + Data
#define CFG_TUD_HID_EP_BUFSIZE 64

#define CFG_TUD_VENDOR            0

// HID buffer size Should be sufficient to hold ID (if any) + Data
#define CFG_TUD_HID_EP_BUFSIZE    64

// CDC FIFO size of TX and RX
#define CFG_TUD_CDC_RX_BUFSIZE   (TUD_OPT_HIGH_SPEED ? 512 : 64)
#define CFG_TUD_CDC_TX_BUFSIZE   (TUD_OPT_HIGH_SPEED ? 512 : 64)

// CDC Endpoint transfer buffer size, more is faster
#define CFG_TUD_CDC_EP_BUFSIZE   (TUD_OPT_HIGH_SPEED ? 512 : 64)

#ifdef __cplusplus
}
#endif

#endif /* _TUSB_CONFIG_H_ */

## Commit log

2022-08-21 PCB project and schematics draft
    [popn_pico.kicad_pcb, popn_pico.kicad_sch]
2022-08-22 Update PCB with libs and 3d models
    [J 2835.step, Tact Switch 4.5mm SMT.step, User Library-PTS645SL95SMTR92-LFS.STEP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]
2022-08-28 Finished layout
    [popn_pico.kicad_pcb, popn_pico.kicad_sch]
2022-08-28 Woking on plate
    [popn_pico_plate.kicad_pcb, popn_pico_plate.kicad_sch]
2022-08-29 First PCB production
    [popn_pico.kicad_pcb]
2022-09-01 Plate go manufacture
2022-09-03 Fixed PCB bug (LED 5v and GND swapped)
    [popn_pico.kicad_pcb, popn_pico.kicad_sch]
2022-09-04 Firmware first commit
    Button and button leds working, no RGB lights, no debouncing.
2022-09-04 Start work on case, just main body yet
    [pico_popn_case.scad]
2022-09-05 Case created with OpenSCAD
    [pico_popn_case.scad, pico_voltex.3mf]
2022-09-10 Case done (and added the missing USB-C slot)
    [pico_popn_case.scad, pico_popn_case.stl, pico_voltex.3mf]
2022-09-13 Screw spacer STL file and some updates to README
    [screw_spacer.scad, screw_spacer.stl]
2022-10-04 3D printed button option
    [popn_keycap.scad, popn_keycap.stl]
2022-10-04 Updated main image with printed buttons
2022-10-05 More accurate keycap socket
    [popn_keycap.scad, popn_keycap.stl]
2022-10-06 Update resin 3d print info
2022-10-15 Finetune some case details (USB and Pico)
    [pico_popn_case.scad, pico_popn_case.stl]
2022-10-15 Finetune the pcb spacer model
    [screw_spacer.scad, screw_spacer.stl]
2023-01-02 LED fade out effects
2023-01-28 LED9 pin changed to support PWM, UF2 firmware updated too
    [popn_pico.kicad_pcb, popn_pico.kicad_sch]
2023-01-28 Update document for PCB modification
2023-03-11 Fixed missing screw holes
    [popn_pico.kicad_pcb]
2024-12-04 Archive Gen 1 Files
    [J 2835.step, Tact Switch 4.5mm SMT.step, User Library-PTS645SL95SMTR92-LFS.STEP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]
2024-12-04 Gen2 PCB begins
    [530470310.stp, 8002A.step, Button Cap.step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]
2024-12-08 PCB v1.0
    [Popn Pico 2 - PCB.dxf, pop_pico2.kicad_pcb, pop_pico2.kicad_sch]
2024-12-10 Theme color with fixed hue code
    [main.c]
2024-12-17 Main picture of popn pico 2
2025-01-06 Guide is ready
    [popn_pico2_base.stl, popn_pico2_panel.3mf, popn_pico2_support.stl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]
2025-01-14 Optimize switch footprints
    [pop_pico2.kicad_pcb]
2025-02-18 Fix file naming
    [popn_pico2_button_seat.stl]
2025-04-04 Cross-reference to Nos Pico
2025-12-25 Smaller pads
    [popn_pico2_base.stl]
2026-06-08 Popn Visa card holder
    [Popn Visa - Base.stl, Popn Visa - Base_Insert.stl, Popn Visa - Panel.3mf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]
2026-06-08 Reduce the risk of panel bend
    [Popn Pico 2 - Panel Combo.3mf]
